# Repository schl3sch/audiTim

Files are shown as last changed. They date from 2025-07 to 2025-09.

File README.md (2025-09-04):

# 🎧 audiTim – SE-Projekt Code-Repository
Dies ist das zentrale Code-Repository für unser Software-Engineering-Projekt **audiTim**.

📝 **👉 Projektdokumentation:**  
Alle Details zur Idee, Architektur, Technik und Ergebnissen befinden sich in der hier beiligenden Dokumentation:  
📎 ./Documentation/ProjektSe/dokumentation.pdf

## 🛠️ Projekt bauen
1. `.env` konfigurieren (siehe `template.env`)
2. Netzwerk erstellen:
    ```bash
    docker network create sensor-net
    ```
3. Container bauen und starten:
    ```bash
    docker compose up --build -d
    ```
4. In [NodeRed](http://localhost:1880) die InfluxNode konfigurieren
5. [Frontend](http://localhost:8081) öffnen

Ports:
- [Frontend](http://localhost:8081)
- [NodeRed](http://localhost:1880)
- [InfluxDB](http://localhost:8086)

## 📐 Programmierkonventionen
Bitte achtet auf folgende grundlegende Regeln im Projekt:

### Allgemein
-  Klare Projektstruktur: Trennung von `frontend`, `backend`, `firmware`, `tools` etc.
-  Sinnvolle Dateinamen, keine Leerzeichen oder Sonderzeichen
-  Kein Code ohne Nutzen: Altlasten & toten Code entfernen
-  sprechende englische Variablen-/Funktionsnamen

### Code-Stil
- **C++ (ESP32):**
  - Einrückung mit 2 Leerzeichen
  - CamelCase für Variablen und Funktionen
  - Funktionskommentare mit im Stil `CODE // Kommentar ` 
- **Python:**
  - PEP8-konform
  - Docstrings für alle Funktionen und Klassen
- **JavaScript/TypeScript:**
  - ESLint-konformer Stil
  - Klar benannte Funktionen & Kommentare bei komplexer Logik

### Code-Richtlinien
- **C++ (ESP32):**
  - Kein Serial.print in finalem Sketch (Braucht zu lange)
  - Kein \#define -> nur const (Einheitlich)
  - Kein while(!init){} (Nicht benötigt)
  - Funktion probeMax4466 muss in den Dateien identisch sein
  - Externe Bibliotheken müssen mit Version angegeben sein

## Testing
docker-compose -d -build --prod um tests in docker laufen zu lassen!

### E2E-Testing 
npx playwright install to install Browsers locally
npx playwright test to run tests
npx playwright test --ui for ui 
npx playwright test --headed for open Browser on testing
npx playwright codegen http://localhost:8081 for testgenerator im Durchlauf

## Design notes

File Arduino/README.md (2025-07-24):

# 🎧 audiTim – SE-Projekt Code-Repository

Dies ist das zentrale Code-Repository für unser Software-Engineering-Projekt **audiTim**.

📝 **👉 Projektdokumentation:**  
Alle Details zur Idee, Architektur, Technik und Ergebnissen befinden sich im zugehörigen Doku-Repository:  
📎 [https://github.com/JD-GG/audiTim-Documentation.git](https://github.com/JD-GG/audiTim-Documentation.git)

## 📐 Programmierkonventionen

Bitte achtet auf folgende grundlegende Regeln im Projekt:

### Allgemein

-  Klare Projektstruktur: Trennung von `frontend`, `backend`, `firmware`, `tools` etc.
-  Sinnvolle Dateinamen, keine Leerzeichen oder Sonderzeichen
-  Kein Code ohne Nutzen: Altlasten & toten Code entfernen
-  sprechende englische Variablen-/Funktionsnamen

### Code-Stil

- **C++ (ESP32):**
  - Einrückung mit 2 Leerzeichen
  - CamelCase für Variablen und Funktionen
  - Funktionskommentare mit im Stil `CODE // Kommentar ` 
- **Python:**
  - PEP8-konform
  - Docstrings für alle Funktionen und Klassen
- **JavaScript/TypeScript:**
  - ESLint-konformer Stil
  - Klar benannte Funktionen & Kommentare bei komplexer Logik

### Code-Richtlinien

- **C++ (ESP32):**
  - Kein delay() nach WiFi init (Stört WiFi)
  - Kein Serial.print in finalem Sketch (Braucht zu lange)
  - Kein \#define -> nur const (Einheitlich)
  - Kein while(!init){} (Nicht benötigt)
  - Funktion probeMax4466 muss in den Dateien identisch sein
  - Externe Bibliotheken müssen mit Version angegeben sein

## 🔀 Git-Workflow (Feature-Branch-Modell)

Wir arbeiten mit einem **Feature-Branch-Modell**, um saubere und nachvollziehbare Entwicklung zu gewährleisten.

### Branches

- `main`: stabile, getestete Versionen
- `feature/<kurzer-namer>´: jeweiliger Feature-Branch

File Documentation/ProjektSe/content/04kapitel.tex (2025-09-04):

\chapter{Softwarekomponenten}

\section{Entwicklungsumgebungen}

Zu Beginn des Projekts wurden zwei gängige Entwicklungsumgebungen für die Programmierung von Mikrocontrollern evaluiert: die klassische \textit{Arduino IDE}, welche auch von den betreuenden Dozierenden empfohlen wurde, sowie die moderne, zunehmend verbreitete \textit{PlatformIO}-Erweiterung für Visual Studio Code.
Im Projektteam wird plattformübergreifend mit Linux, Windows 10 und Windows 11 gearbeitet. Beide Entwicklungsumgebungen sind grundsätzlich mit allen eingesetzten Betriebssystemen kompatibel. Zur Prüfung der technischen Umsetzbarkeit wurden zwei separate Repositories eingerichtet, in denen jeweils einfache Testprojekte zur Ansteuerung eines ESP32 implementiert wurden.
Beide IDEs konnten den Mikrocontroller erfolgreich ansprechen. PlatformIO bietet durch seine deklarative Verwaltung von Bibliotheken und Abhängigkeiten Vorteile in Bezug auf Reproduzierbarkeit und Build-Konsistenz. In der Praxis kam es jedoch auf einem System im Team zu anhaltenden technischen Problemen mit PlatformIO, die nicht zufriedenstellend gelöst werden konnten.
Um eine einheitliche und zuverlässige Entwicklungsgrundlage für alle Teammitglieder sicherzustellen, fiel die Entscheidung letztlich zugunsten der \textit{Arduino IDE}. Diese ermöglicht eine barrierefreie Mitarbeit aller Beteiligten, auch wenn sie im Funktionsumfang nicht ganz an PlatformIO heranreicht.

\section{Kommunikationsmethode}
ESP-NOW wurde ausgewählt, da es im Vergleich zu anderen Protokollen einen deutlich geringeren Overhead besitzt und dadurch eine schnellere und effizientere Datenübertragung ermöglicht. Die Struktur ist weniger komplex, was die Implementierung vereinfacht und die Fehleranfälligkeit reduziert. 
Dadurch wird das System insgesamt robuster und zuverlässiger:
ESP-Now ist ein Kommunikationsprotokoll von Espressif, das speziell für die ESP32- und ESP8266-Chips entwickelt wurde. Es verwendet die 2,4 Ghz Frequenz, welche eigentlich für WiFi Kommunikation verwendet wird. 
Im Gegensatz zu anderen Protokollen sind die Nachrichten auf Schicht 2 des ISO-OSI-Modells. Keine IP-Adressen sondern nur MAC-Adressen. Die ESPs müssen sich dafür im gleichen Kanal befinden. Die 2,4 Ghz Frequenz hat grundsätzlich nur 3 Nutzbare Kanäle. 
Der zu verwendene Kanal muss von dem "AI401" Wlan Netz übernommen werden.Es ist mit relativ wenig Code möglich eine große Menge an Daten in sehr Kurzen Zeitabschnitten zu senden. Theoretisch ist eine Datenübertragung von 1 bis 2 Mbps möglich. 
Die Nachrichtenlänge ist auf 250 Byte pro Paket beschränkt. Da unsere Nachrichten nur wenige Bit lang sind, haben wir hier keine Probleme. 
Das Protokoll hat keine festgelegten Sender/Empfänger Rollen. Jeder ESP kann senden und empfangen. In unserem Beispiel senden aber 3 ESPs und ein Edge-Device empfängt alle Daten. 
Es wird 10 mal pro Sekunde der Lautstärkepegel erfasst und gesendet.

\section{Frontend}
\subsection{Technologieauswahl}
Für die Umsetzung des Frontends wurde das Framework \textit{Angular} gewählt. 
Diese netschiedung basiert auf technischen Faktoren und persönlichen Preferenzen. 
Angular bietet eine klare Struktur durch komponentenbasiertes Design und ist für die moderne Webentwicklung gut geeignet.
Es erleichtert die Wiederverwendbarkeit von eigenen aber auch externen UI-Elementen und unterstützt eine saubere Trennung von Logik und Darstellung. 

Im Vergleich dazu ist \textit{React} ein von Meta entwickeltes UI-Framework. 
\textit{Angular} und \textit{React} haben beide eine komponentenbasierte Architektur. 
Diese Komponenten sind innerhalb anderer Komponenten wiederverwendbar und somit endlos wiederverwertbar. 
Beide sind Open Source. Daher haben React und Angular große Entwicklergemeinschaften, die die Ressourcen regelmäßig erweitern.
Angular ist ein vollwertiges Framework, während React eine JavaScript-Bibliothek ist. 
Deshalb muss React mit einem Framework gepaart werden, um eine schnelle, schöne und kompatible Benutzeroberfläche zu erstellen. 
\cite{kinsta2023angularvreact}

Da außerdem im Team bereits umfangreiche Erfahrung mit diesem Framework vorhanden war, fiel die Entscheidung zugunsten von Angular.
Das Frontend läuft in einem eigenen Docker-Container und kommuniziert, über ein internes Netzwerk, mit dem separat laufenden Backend-Container. 
So bleibt die Architektur modular, skalierbar und einfach wartbar.

\subsection{Umsetzungsplan}
Während der Entwicklung wurde ein einfaches Frontend zu Testzwecken angelegt. 
Deshalb soll nun ein Plan entwickelt werden, wie die Benutzeroberfläche aussehen soll und welche Funktionen sie bieten soll:
\begin{center}
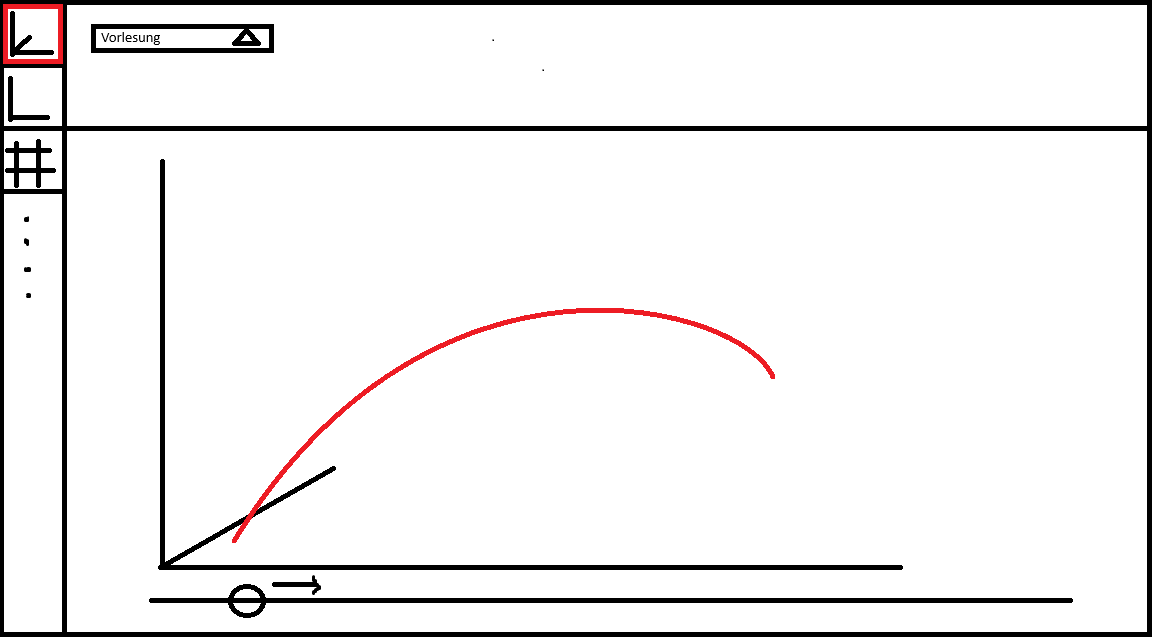
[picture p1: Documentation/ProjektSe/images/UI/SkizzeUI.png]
  
\end{center}
In dieser Skizze wurden die Grundfunktionen der Benutzeroberfläche festgelegt und die Anordnung der einzelnen Elemente skizziert.
Über eine Navbar an der linken Seite kann zwischen den einzelnen Seiten gewechselt werden. 
Auf der Hauptseite wird eine Heatmap angezeigt, die die Lautstärkeverteiung im Vorlesungsraum räumlich darstellt, wobei mit einem Dropdown-Menü der anzuzueigende Zeitraum ausgewählt werden kann.
Durch den ausgewählten Zeitraum kann anschließend mit einem Schieberegler die Zeit ausgewählt werden, für die die Lautstärke angezeigt werden soll.
Im nächsten Nav-Item sollen die einzelnen 2D-Grafen der jeweiligen Sensoren angezeigt werden. 
Das dritte Nav-Item soll einen tabellarischen Überblick über die gesammelten Daten geben, die in der Datenbank gespeichert sind.
Die Nvabar bietet Raum für zukünfitge Erweiterungen.

\subsection{Umsetzung}
Auf Grundlage dieser Skizze wurde das Frontend und UI efolgreich umgesetzt.
So hat man nun eine übersichtliche Homepage, die auf alle Elemente verweist, welche auch in der interaktiven Navbar zu finden sind.
Als kleines AddOn wurde unteranderem hierfür ein "AudiTim" Logo entworfen, was den ikonischen Hirsch mit dem vernetzten Geweih und den Audiowellen verknüpft, sowie eine Light- und Darkmode Funktionalität implementiert.
\begin{center}
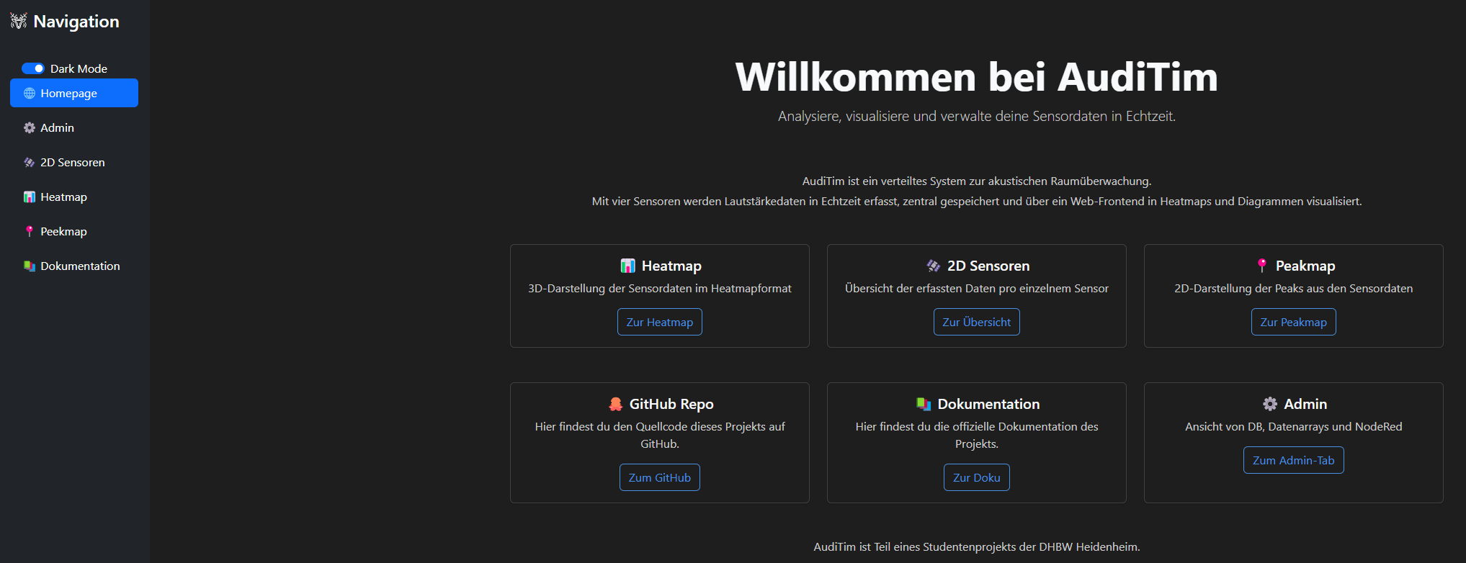
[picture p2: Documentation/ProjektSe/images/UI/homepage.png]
  
\end{center}

Auch im Screenshot zu sehen, sind die schlussendlich umgesetzten Seiten; Heatmap, 2D-Sensoren, Peakmap, Github Repo, Dokumentation und Admin. 
Für diese Seiten wurden die in der Skizze angedachten Funktionen erfolgreich umgesetzt und flexibel während der Entwicklung angepasst und erweitert.

So zeigt die Admin-Seite nun eine Übersicht über die verbundenen Container und Elemte sowie deren Status an:
\begin{center}
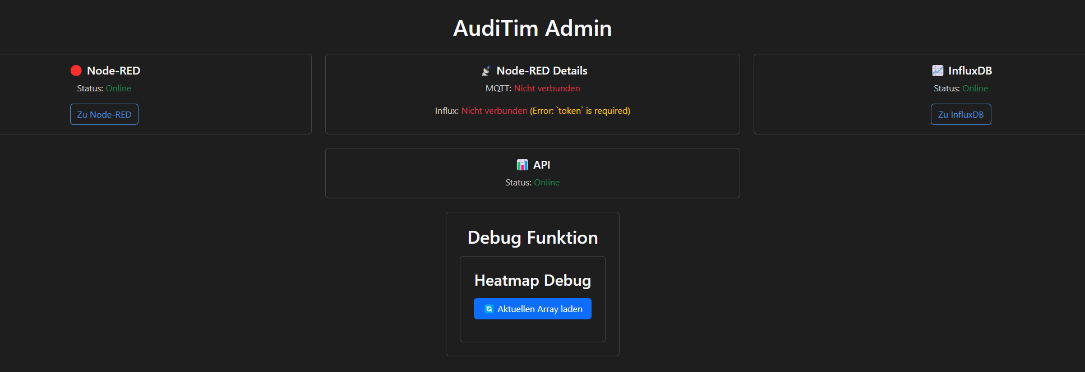
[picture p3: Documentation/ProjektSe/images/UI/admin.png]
  
\end{center}

Die 2D-Sensoren-Seite zeigt die einzelnen Sensorwerte in übersichtlichen Liniendiagrammen an, wobei man zwischen einem ausgewählten Zeitraum und einem Live-Modus wechseln kann:
\begin{center}
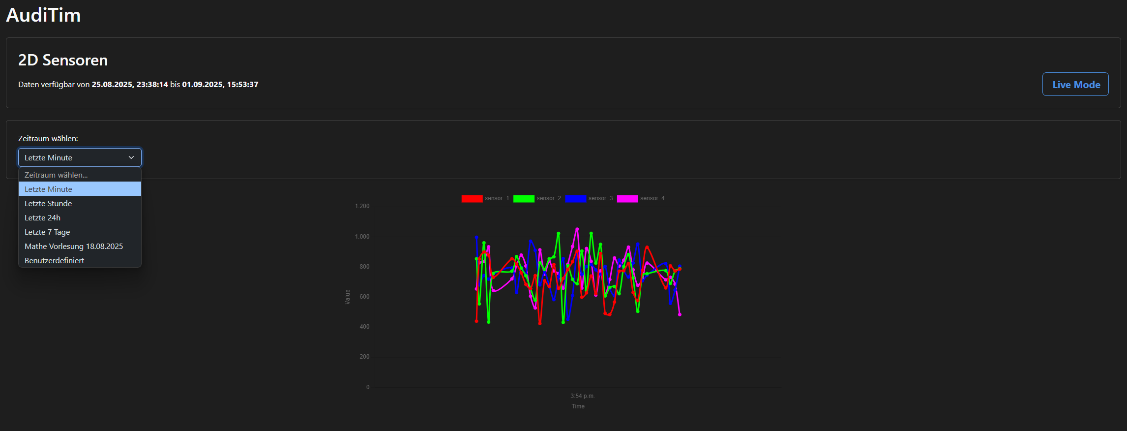
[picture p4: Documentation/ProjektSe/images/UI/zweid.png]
  
\end{center}

Auch die Heatmap-Seite zeigt die Auswahl zwischen einem ausgewählten Zeitraum und einem Live-Modus, sowie einen Average-Modus, in dem die durchschnittliche Lautstärke über den ausgewählten Zeitraum angezeigt wird. 
Mit einem Schieberegler kann die Zeit innerhalb des ausgewählten Zeitraums angepasst werden und gegenenenfalls eine Animation gestartet werden, die die Lautstärkeverteilung über den Zeitraum hinweg anzeigt.
Außerdem wurde das in "4.5 3D-Raummodellierung" beschriebene 3D-Modell des Raumes als Hintergrundbild für die Heatmap verwendet, um eine realistische Darstellung zu ermöglichen:
\begin{center}
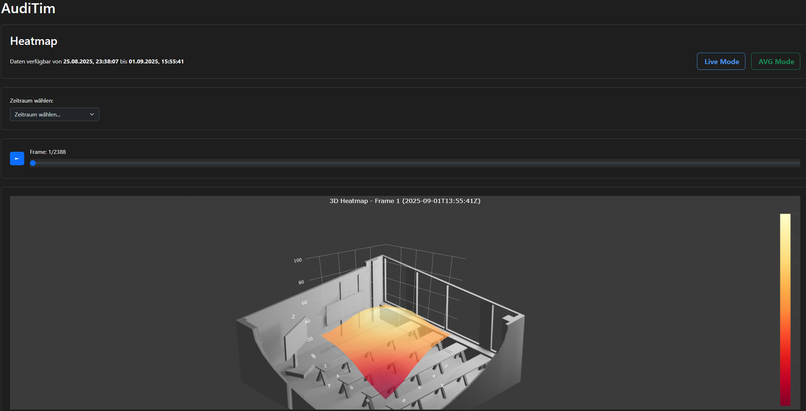
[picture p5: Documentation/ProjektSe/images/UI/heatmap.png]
  
\end{center}

Dieses 3D-Modell wurde auch für die Peakmap-Seite verwendet, auf der die Spitzenwerte der Sensoren über den ausgewählten Zeitraum angezeigt werden:
\begin{center}
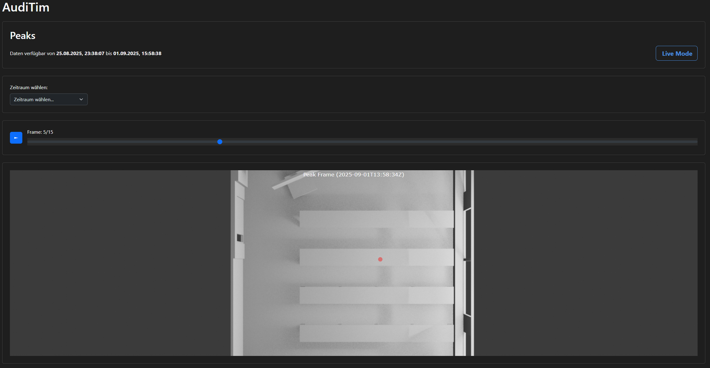
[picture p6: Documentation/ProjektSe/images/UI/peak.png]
  
\end{center}

Und zu guter Letzt zeigt die Dokumentation-Seite diese Dokumentation, die sie hier gerade lesen, in einem eingebetteten PDF-Viewer an. 

\subsection{Testing}
Für die Umsetzung des automatisierten Testings wurde Playwright eingesetzt. Die Auswahl dieses Frameworks erfolgte nach einer vergleichenden Analyse. Dabei wurde Playwright von einem Teammitglied im Rahmen einer Projektarbeit mit einem ähnlichen Anwendungsfall ausführlich evaluiert und als am geeignetsten bewertet. Ausschlaggebend hierfür waren insbesondere die breite Browserunterstützung, die integrierten Funktionen für End-to-End-Tests sowie die hohe Stabilität und Geschwindigkeit der Testausführung.

Durch den Einsatz von Playwright konnte die Konsistenz der Benutzeroberfläche (UI) zuverlässig sichergestellt werden. Die automatisierten Tests ermöglichen es, Interaktionen und Darstellungsvarianten reproduzierbar zu prüfen und so frühzeitig Abweichungen oder Fehler zu erkennen. Auf diese Weise trägt das Testing wesentlich zur Qualitätssicherung und Nachhaltigkeit der entwickelten Lösung bei.

\section{Backend}
Das Backend wurde mit Node.js und dem minimalistischen Framework Express.js umgesetzt. 
Express ist das am weitesten verbreitete Node.js-Framework für Webserver und APIs. 
Es bietet eine ausgereifte Middleware-Architektur, die sehr flexibel und modular ist. 
Im Vergleich zu ähnlich minimalistischen Frameworks wie Koa, 
das von den gleichen Entwicklern stammt, 
bietet Express mehr out-of-the-box Funktionalitäten und eine größere Community mit umfangreichen Plugins und Support. \cite{betterstack2025koavsexpress,appventurez2025nodejsframework}

Koa hingegen ist moderner und basiert stärker auf ES6 Features wie async/await, was den Code oft sauberer macht. 
Allerdings ist Koa weniger „batteries included“ und erfordert mehr Initialaufwand und zusätzliche Libraries, 
um Funktionen bereitzustellen, die Express standardmäßig mitbringt. 
Für dieses Projekt, welches einen schnellen Einstieg, umfangreiche Dokumentation und stabile Middleware braucht, 
ist Express daher die pragmatischere Wahl.
Zudem sind Gruppenmitglieder bereits mit Express vertraut, was die Einarbeitungszeit verkürzt und die Produktivität steigert. 

Die Anbindung an eine InfluxDB erfolgt über die offizielle Client-Bibliothek. 
Neben dem Abrufen historischer Sensorwerte werden auch Funktionen zum Schreiben von Dummy-Daten bereitgestellt.
Diese werden, solange die Verbindung zu den wirklichen Sensorwerten noch nicht hergestellt ist, zum Testen verwendet.

Für die Speicherung der Sensordaten wurde InfluxDB gewählt. 
Eine Zeitreihen-Datenbank, die speziell für viele konsekutive Datenströme optimiert ist. 
InfluxDB bietet eine simple API und gutes visuelles UI, ohne dass viel Konfiguration nötig ist.
Im Vergleich zu einer relationalen Datenbank wie TimescaleDB, die auf PostgreSQL basiert,
ist InfluxDB deutlich einfacher zu handhaben und benötigt weniger Overhead für die Konfiguration.
Um eine TimescaleDB sicher zum laufen zu bringen, sind komplexe Zugriff-Skripte benötigt, um die Benutzer zu verwalten.
InfluxDB hingegen arbeitet mit einem einfachen Benutzer- und Rollenkonzept. 
Auch für die API-Authentifizierung ist InfluxDB mithilfe von Tokens und Secrets deutlich einfacher zu konfigurieren.
Der Rationale Aspekt einer traditionellen ist sicherlich in vieler Hinsicht nützlich, wird aber in diesem Projekt nicht benötigt.
Eine nahtlosen Integration in das Node.js-Backend ist mit der offiziellen InfluxDB-Bibliothek kein Problem.
InfluxDB wurde uns initial von den "Verteilten Systeme"-Dozenten ausdrücklich empfohlen, da wir viele Zeitwerte speichern und analysieren wollen.

\subsubsection*{Berechnung des Speicherplatzbedarfs für InfluxDB}

Zur Abschätzung des benötigten Speicherplatzes in InfluxDB betrachten wir die anfallenden Sensordaten pro Stunde.  

\paragraph{Rohdaten}  
Pro Sekunde werden \textbf{10 Messungen} von \textbf{4 Sensoren} erfasst, wobei jeder Wert als \texttt{double} (64\,Bit = 8\,Byte) gespeichert wird.  
Damit ergibt sich:  

\[
10 \times 4 \times 8 \,\text{Byte} \times 60 \times 60 
= 1{,}152{,}000 \,\text{Byte} \approx 1.1 \,\text{MB/h}
\]

\paragraph{Base64-kodierte Daten}  
Wird der Algorithmus auf die Sensordaten angewendet, erzeugt er daraus ein 10x10-Array mit Werten im Bereich von 0 bis 255. Dieses Array wird anschließend kodiert. Durch die Base64-Kodierung entsteht dabei ein Overhead von etwa 36\%. Für die Datenmenge ergibt sich pro Sekunde:  

\[
800 \,\text{Bit} = 100 \,\text{Byte} \quad \Rightarrow \quad 
\text{mit Overhead} \approx 136 \,\text{Byte}
\]

Somit pro Stunde:  

\[
136 \,\text{Byte} \times 60 \times 60 
= 489{,}600 \,\text{Byte} \approx 470 \,\text{KB/h}
\]

\paragraph{Fazit}  
Für die Speicherung in InfluxDB müssen daher pro Stunde etwa  
\[
1.1\,\text{MB (Rohdaten)} + 0.47\,\text{MB (Base64)} \approx 1.6\,\text{MB/h}
\]  
eingeplant werden.

Das Backend ist ebenfalls in einem eigenen Docker-Container gekapselt. 
Die Kommunikation mit dem Frontend erfolgt über definierte HTTP-Endpunkte im Container-Netzwerk. 
Diese Trennung verbessert die Wartbarkeit und erlaubt eine flexible Skalierung beider Komponenten unabhängig voneinander.

\section{MQTT Subscriber}
Um den Datenfluss zu verfollständigen fehlt eine Brücke zwischen dem MQTT Server und der InfluxDB. 
Hierfür wird ein sogenannter MQTT-Subscriber benötigt, der die Daten vom MQTT-Broker abonniert und in die InfluxDB schreibt.
Technisch gesehen kann dies mit einer vielzahl von Frameworks / Sprachen / Tools umgesetzt werden. 
Zum Beispiel mit Python, Node.js, Golang oder auch Java.
Wir haben uns für Node-RED entschieden, da es eine einfache und schnelle Möglichkeit bietet, um Daten von MQTT zu InfluxDB zu übertragen.
Node-RED ist eine visuelle Programmierumgebung, die auf Node.js basiert und es ermöglicht, Datenströme einfach zu verarbeiten und zu transformieren.
Besonders das debugging und die Visualisierung der Datenströme ist in Node-RED sehr einfach und intuitiv.
\cite{nodered2023docs}

Im Vergleich zu z.B. einem Python-Skript ist Node-RED deutlich einfacher zu handhaben.
Natürlich ist Node-RED nicht so performant oder bietet dieselbe Flexibilität und Kontrolle wie ein selbstgeschriebenes Skript,
ist aber dafür deutlich einfacher zu konfigurieren und zu warten.
Besonders in unserem spezifischen Fall, wo wenig Kontrolle über den schlussendlichen Server besteht, ist Node-RED eine gute Wahl.
Eine automatische Ausführung von Skripten ist beinahe unmöglich, das keine Kontrolle über Sudo-Level Systemdiensten besteht.

\subsection{NodeRED Umsetzung}
Node-RED stellte sich als eine gute Entscheidung heraus, um den Flow zwischen MQTT und InfluxDB zu realisieren, und aber auch um bspw. Statusanfragen für die Admin-Seite zu beantworten.
Das einzige Manko war das ständige Erneuern der Tokens für die InfluxDB, da Node-RED keine Möglichkeit bietet, Umgebungsvariablen zu verwenden.
Schlussendlich entstand ein gut-funktionierender Flow:
\begin{center}
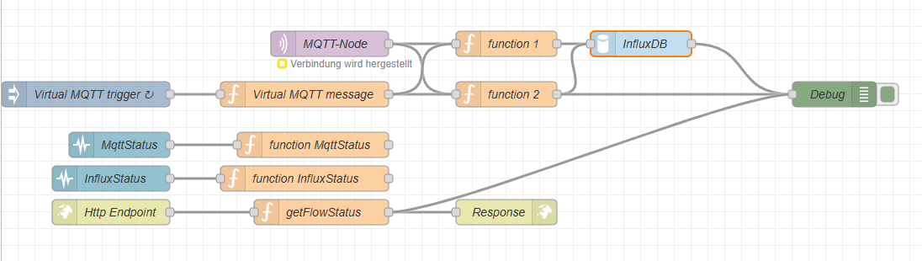
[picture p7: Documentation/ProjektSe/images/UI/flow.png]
  
\end{center}

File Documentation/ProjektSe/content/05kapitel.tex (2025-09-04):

\chapter{Befestigung der Hardware}
\label{chap:Befestigung_der_Hardware}
Um die Hardware des AudiTim-Systems sicher und stabil zu befestigen, sind verschiedene Montagemöglichkeiten verfügbar. 
Ein Großes Problem bei vorgefertigten halterungen ist jedoch, dass diese oft an die and geschraubt oder anderweitig befestigt werden müssen.
Daher fiel für unser Projekt die wahl auf eine selbst designte Halterung, welche in einem 3D-Drucker hergestellt werden kann.
Dies Garantiert dass keine schäden an der Hardware oder am Raum in welchem die Hardware montiert wird entstehen.

\section{Platzungskonzept}
Aus akustischer Sicht liefern Messungen die zuverlässigsten Ergebnisse, wenn die Sensoren auf Kopfhöhe im Sitzen (~1,2-1,5 m Höhe) angebracht sind und mindestens 1 Meter Abstand zu Wänden und der Schallquelle haben. 
Dieses Vorgehen minimiert frühe Reflexionen, stehende Wellen und lokale Pegelabweichungen - Faktoren, die die Messgenauigkeit maßgeblich beeinträchtigen \cite{oltheten2019micplacement} .
Leider ist diese ideale Positionierung in unserem Fall praktisch nicht umsetzbar. So birgt Montage am Boden, Tischen oder gesonderte "Ständer" erhöhte Gefahr von Beschädigungen, Verschiebungen und Manipulation.
An der Decke jedoch beifinden sich bereits vorhandene Löcher; diese können genutzt werden, um die Sensoren und den Mikrocontroller sicher zu befestigen. 
Auch den einen Meter Abstand zu Wänden und Schallquellen kann so eingehalten werden.
Dieser Kompromiss ermöglicht eine schützende, wartungsarme und vergleichbare Positionierung der Sensoren.
So bleibt der Messaufbau reproduzierbar, sicher und funktional, auch wenn die akustisch ideale Lösung nicht vollständig umsetzbar ist.

\section{Deckenhalterung}
Um die Hardware an der Decke zu befestigen, wurde eine spezielle Halterung entworfen, die eine sichere Montage ermöglicht.
Diese Halterung nutzt die in den Decken vorhandenen "Löcher" für die Montage und wurde als eine Art Pin konzipiert.

\begin{center}
  \begin{minipage}[b]{0.32\textwidth}
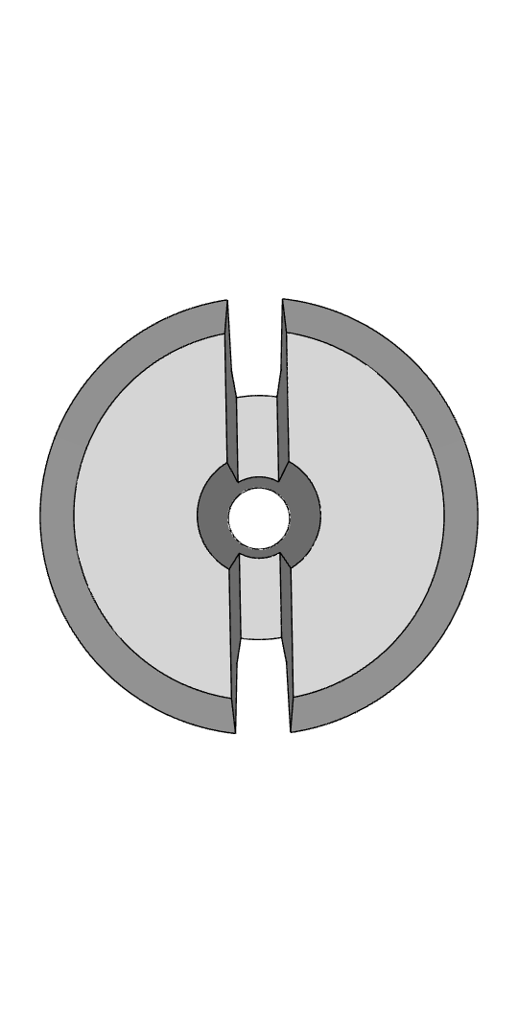
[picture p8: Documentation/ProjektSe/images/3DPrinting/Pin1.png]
    
  \end{minipage}
  \hfill
  \begin{minipage}[b]{0.32\textwidth}
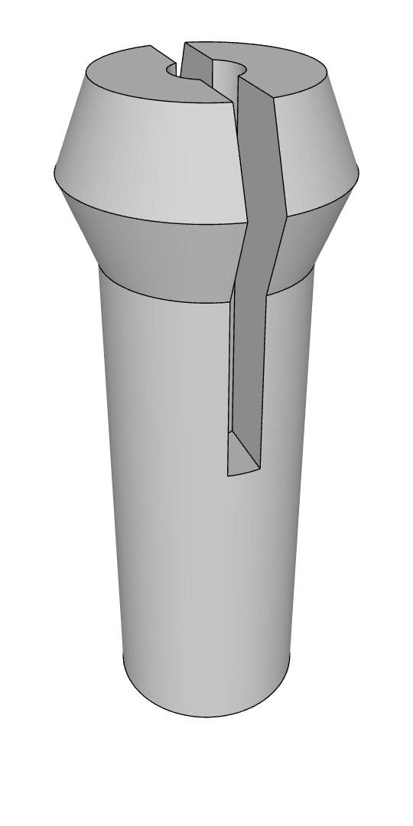
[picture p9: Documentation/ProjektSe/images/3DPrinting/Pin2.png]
    
  \end{minipage}
  \hfill
  \begin{minipage}[b]{0.32\textwidth}
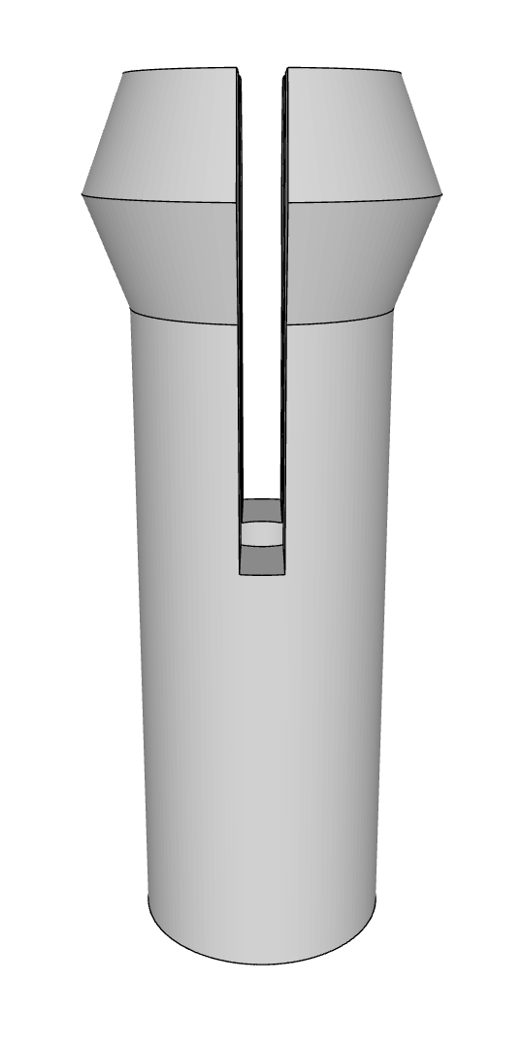
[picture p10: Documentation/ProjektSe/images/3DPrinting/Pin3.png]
    
  \end{minipage}
\end{center}

Der in den Bildern Dargestellte Pin kann durch den Spalt in der Mitte in die öffnung der Decke gesteckt werden.
Durch die Konische form der Spitze des Pins wird garantiert dass dieser auch bei der Demontage des Projekts keine schäden hinterlässt.
Das runde loch welches sich durch den Pin zieht dient dazu, den Pin mit einer Schraube an der Hardware zu befestigen.

\section{ESP32-Halterung}
Der Esp benötigt eine Box welche sicher an der Decke mit den Pins befestigt werden kann.
Bei dem Design der Box wurde sich an einigen Vorlagen orientiert um eine optimale Passform zu gewährleisten.
Die Box ist so gestaltet, dass sie den ESP32 sicher hält und gleichzeitig genug Platz für die Verkabelung bietet.

\begin{center}
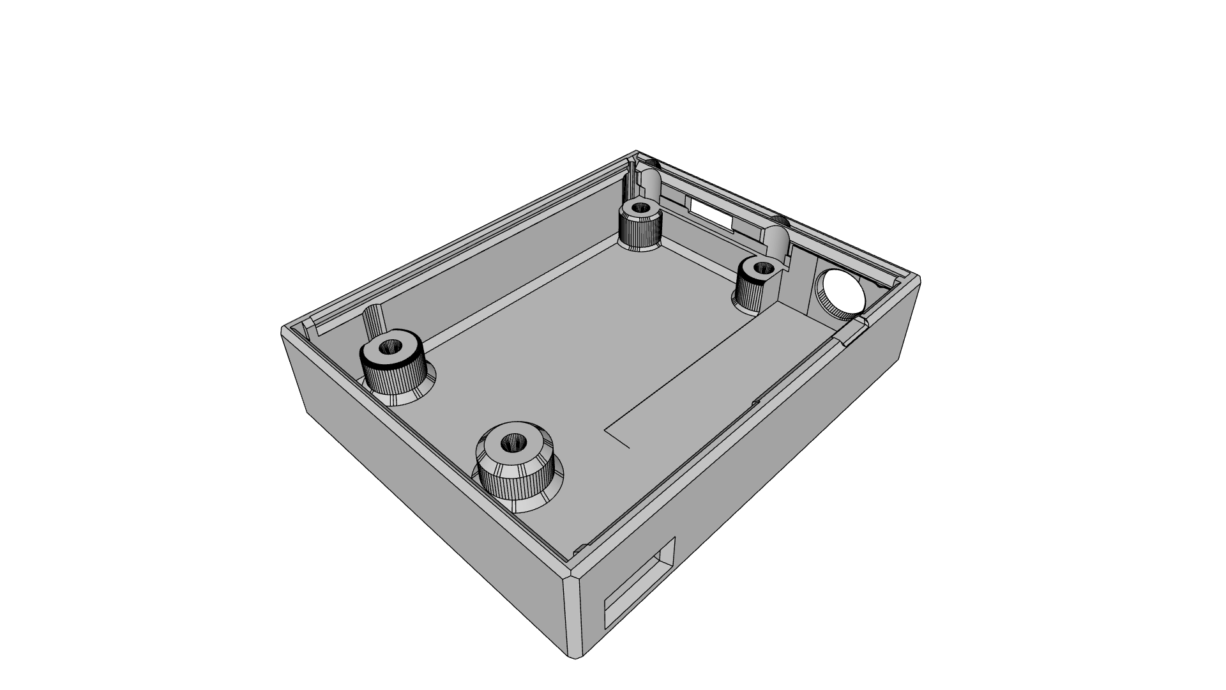
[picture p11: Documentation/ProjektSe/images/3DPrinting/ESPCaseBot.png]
  
\end{center}

Die angesprochenen löcher der Pins kommen in der Decke der Box zum Einsatz, um die Box sicher an der Decke zu befestigen.
Diese werden durch die löcher in der Decke mit schrauben von innen befestigt.

\begin{center}
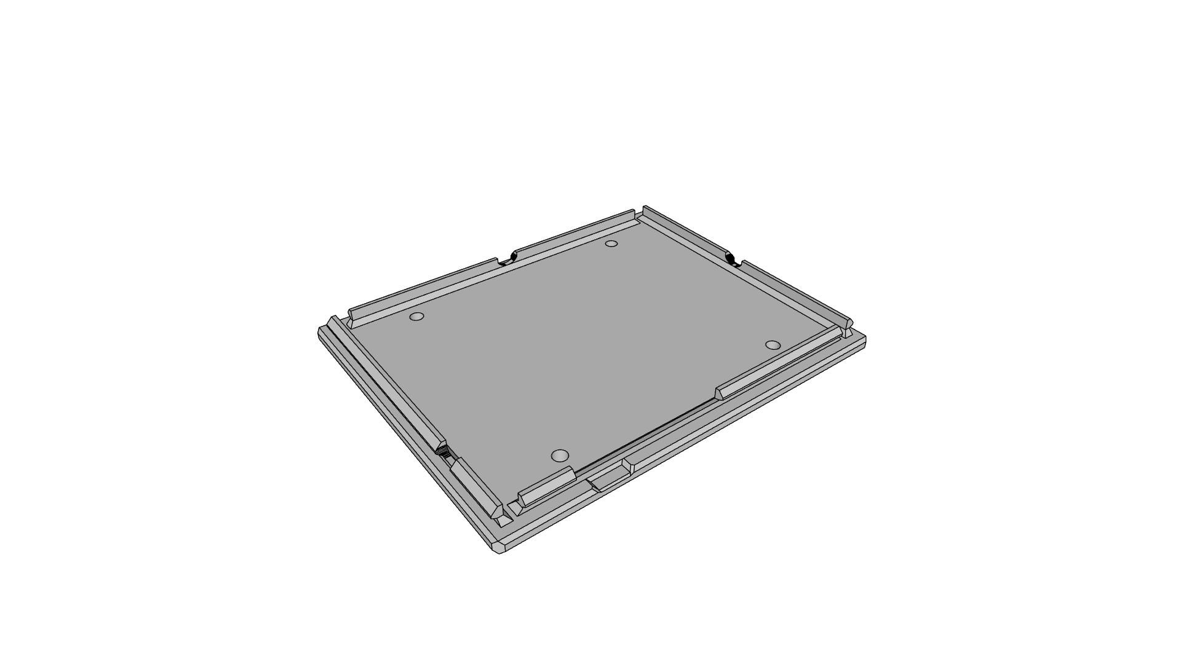
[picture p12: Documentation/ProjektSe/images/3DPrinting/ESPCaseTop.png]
  
\end{center}

\section{Sensor-Halterung}

Die Sensorhalterung wurde so entworfen dass sie platz für einen möglichen Dämpfer bietet,
welcher um das Mikrofon befestigt werden kann.
Auch diese Halterung wird mit den Pins an der Decke befestigt, jedoch wird sie nicht geschraubt sondern direkt mit den Pins gedruckt.
Der Sensor wird dann einfach mit zwei schrauben an der Halterung befestigt.

\begin{center}
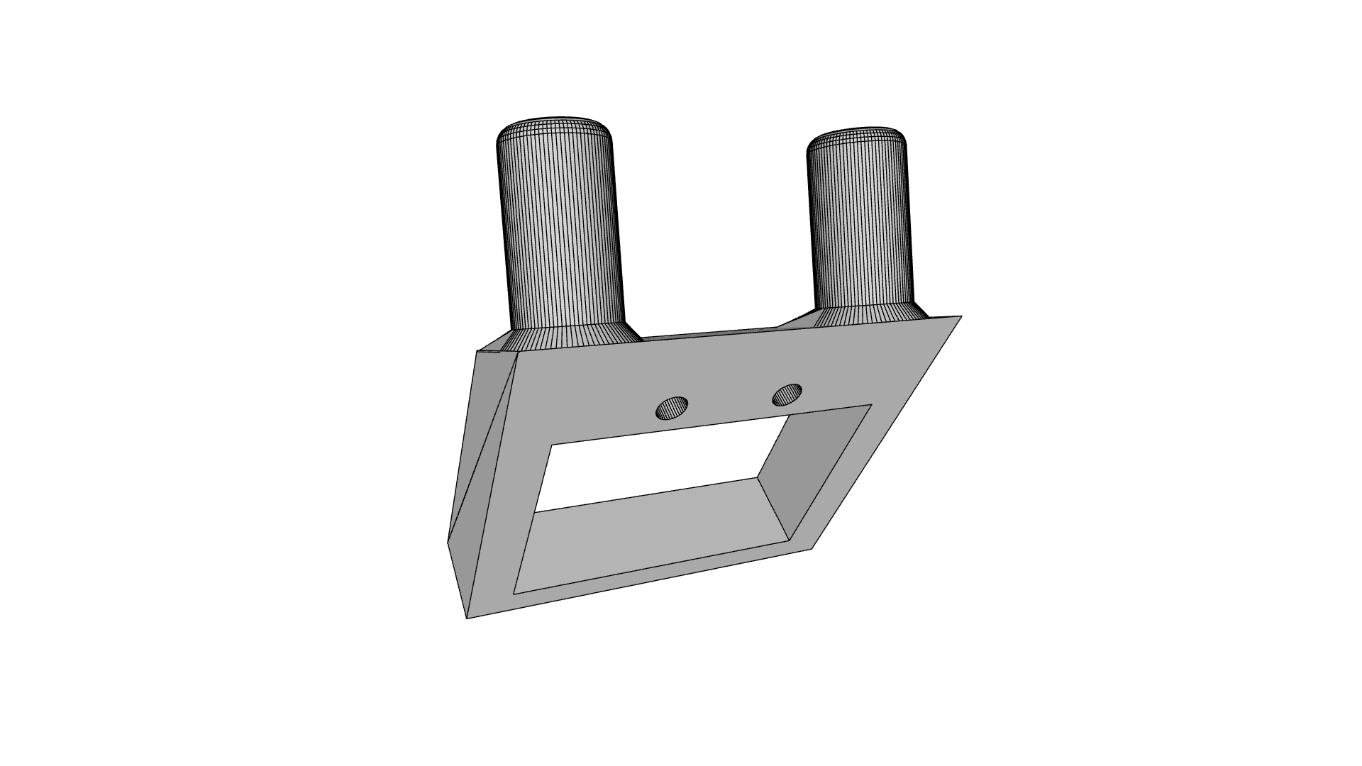
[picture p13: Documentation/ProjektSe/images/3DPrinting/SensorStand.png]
  
\end{center}

\section{3D-Raummodellierung}
Um eine grafische Übersicht der Montage der ESPs und Sensoren zu erhalten, wurde ein 3D-Modell des Raumes erstellt.
Außderdem soll dieses später als Grundlage für die Simulation der Schallausbreitung als Hintergrund für die Heatmap im Frontend dienen.
Dafür wurde vorerst der Vorlesungsraum ausgemessen und in einer technischen Zeichnung festgehalten:
\begin{center}
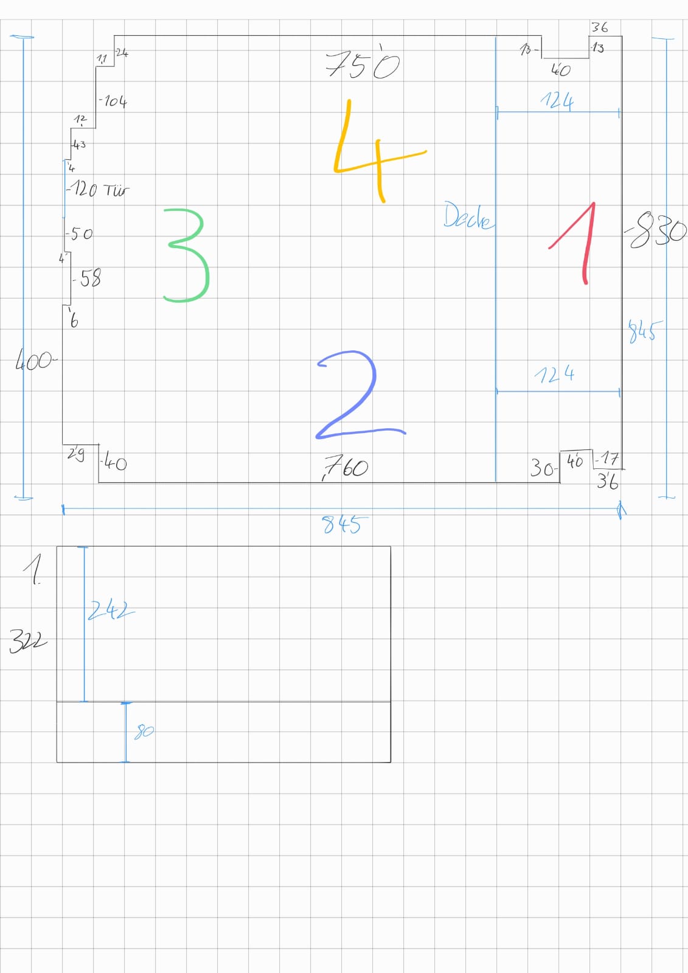
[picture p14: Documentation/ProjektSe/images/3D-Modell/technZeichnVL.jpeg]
  
\end{center}
Diese Zeichnung dient als Grundlage für die 3D-Modellierung des Raumes, welche in Blender durchgeführt wurde:
\begin{center}
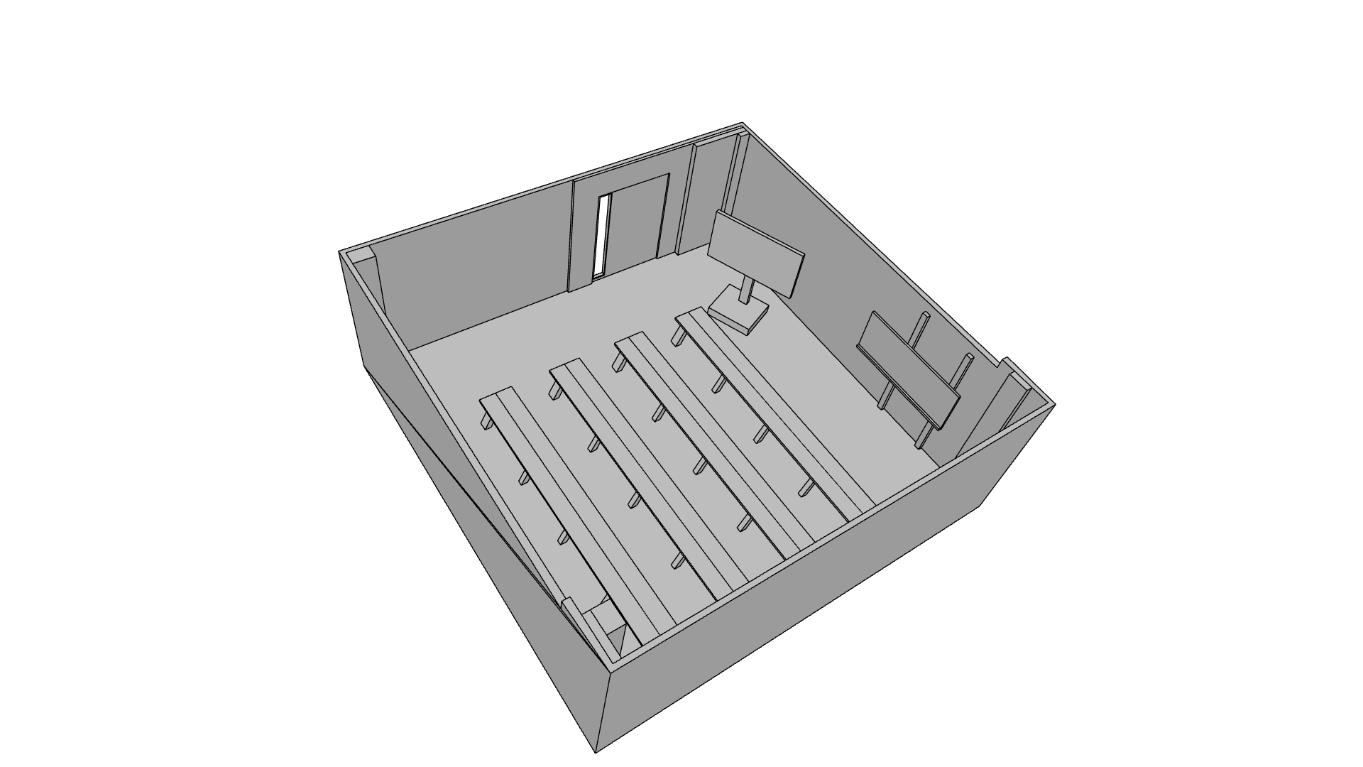
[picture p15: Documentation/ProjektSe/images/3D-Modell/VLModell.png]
  
\end{center}

\paragraph{Hinweis zur Nutzung der 3D-Modelle}  
Die im Projekt erstellten Blender-Dateien und Halterungen können direkt für den 3D-Druck verwendet werden.  
Zum Export der STL-Dateien ist im Blender-Menü der Pfad \texttt{audiTim/Blender/Printable} zu wählen.

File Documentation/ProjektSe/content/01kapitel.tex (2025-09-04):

\chapter{Einleitung}
\label{cha:einleitung}

Im Rahmen des Software-Engineering-Projekts wird in einem Team ein System zur akustischen Raumüberwachung entwickelt. 
Ziel des Projekts ist die kontinuierliche Erfassung und spätere Analyse der Lautstärkeverteilung in einem typischen Vorlesungsraum über den Zeitraum mehrerer Tage hinweg.

\section{Projektüberblick}

Die Umsetzung erfolgt nach agilen Prinzipien unter Anwendung von Scrum, wobei die jeweiligen Sprints von Freitag bis Freitag festgelegt wurden. 

Die technische Architektur sieht den Einsatz von vier Mikrocontroller-Einheiten (ESP32) vor, die jeweils mit einem Mikrofon oder einem Dezibel-Messsensor ausgestattet werden. 
Die Geräte werden in den vier Ecken des Vorlesungsraums positioniert, um eine möglichst flächendeckende Abdeckung des Raumes zu gewährleisten. Über ein Kommunikationsprotokoll tauschen sich die ESPs untereinander aus und 
senden die gesammelten Messdaten gemeinsam an ein zentrales Backend.

\section{Ziele und Motivation}

Ziel ist es, ein skalierbares und robustes System zu entwickeln, das Lautstärkepegel über einen längeren Zeitraum erfassen kann. Die gesammelten Daten sollen im Backend gespeichert und im Nachgang analysiert werden. 
Hierbei sind verschiedene Darstellungsformen wie etwa Heatmaps oder zeitbasierte Diagramme denkbar, um Muster oder Auffälligkeiten im akustischen Verhalten des Raumes sichtbar zu machen.

\section{MVP und Qualitätsmerkmale}

Im Rahmen des MVPs soll ein verteiltes System zur akustischen Raumüberwachung auf Basis von vier Mikrocontrollern der ESP-Serie entwickelt werden. 
Jeder ESP wird über ein extern angeschlossenes Mikrofon verfügen, mit dem kontinuierlich Lautstärkedaten erfasst werden. Drei der Module sollen ihre Messwerte mithilfe des ESP-NOW-Protokolls an eine zentrale Einheit übermitteln, 
die zusätzlich eigene Daten erfasst. Die aggregierten Informationen aller vier Einheiten werden in festen Intervallen über das MQTT-Protokoll an einen Server gesendet und dort zeitsynchron in einer InfluxDB gespeichert. 
Über eine REST-API sollen die Daten einem Angular-basierten Web-Frontend zur Visualisierung der akustischen Messwerte zur Verfügung gestellt werden.

\begin{center}
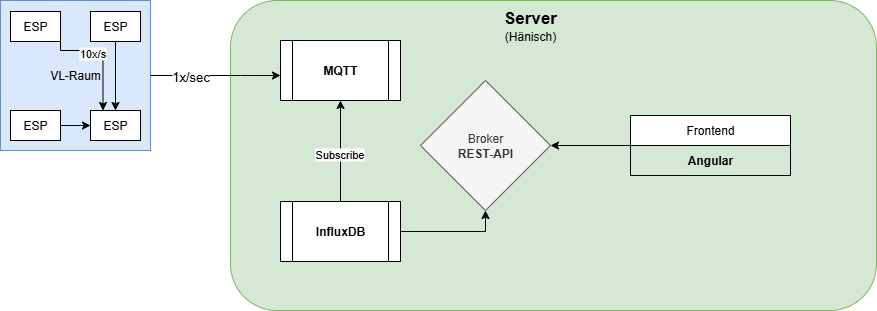
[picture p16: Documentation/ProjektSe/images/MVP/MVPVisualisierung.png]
  
\end{center}

Aufgrundlage des MVPs sollen die folgenden Qualitätsmerkmale sichergestellt werden:
\begin{itemize}
    \item \textbf{Echtheit \& Qualität der Daten:}
    Nur qualitative Daten z.B. durch manuelle Überprüfung und Kalibrierung der Mikrofone ermöglichen realistische Messwerte und damit eine sinnvolle Analyse der akustischen Verhältnisse im Raum.
\item \textbf{Accountability der Daten:}
    Es muss nachvollziehbar sein, welche Sensoren zu welchem Zeitpunkt welche Daten erfasst haben. Diese Anforderung soll durch das Einführen einer eindeutigen ID für jeden Sensor, die mit jedem Value mitgeschickt wird, umgesetzt werden.
    \item \textbf{Verfügbarkeit:}
    Da die Übertragungswege mit ESP-NOW und MQTT unterbrochen werden könnten ist es wichtig die Verfügbarkeit von Daten sicherzustellen indem ein möglicher Ausfall schnellstmöglich erkannt wird um diesen dann beheben zu können. Dies soll sichergestellt werden durch die Einführung einer Notification, die ausgelöst wird beim Ausfall eines Gerätes, was final über einen eigenen Discord-Server bereitgestellt werden soll.
\end{itemize}

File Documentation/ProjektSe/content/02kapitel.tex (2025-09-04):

\begin{landscape}
\chapter{SFMEA-Analyse}
\section{Analyse}
\label{cha:sfmea}
\small
\begin{longtable}{|p{3.4cm}|p{3.4cm}|p{3.4cm}|p{3.4cm}|c|c|c|c|p{3.4cm}|}

    \hline
    \textbf{Systemfunktion} & \textbf{Fehlermöglichkeit} & \textbf{Fehlerursache} & \textbf{Fehlerfolge} & \textbf{B} & \textbf{A} & \textbf{E} & \textbf{RPZ} & \textbf{Maßnahmen} \\
    \hline
    \endhead

    Dezibel erfassen & Falsche oder keine Messwerte & Mikrofon defekt, Sensor ungeeignet & Ungenaue oder keine Daten & 8 & 6 & 3 & 144 & Robuste Mikros, Kalibrierung, Ersatzsensor bereit \\
    \hline
    ESP kommuniziert nicht mit anderen & Keine oder fehlerhafte Datenübertragung & WLAN-Probleme, falsches Protokoll & Daten gehen verloren, keine Heatmap & 7 & 5 & 4 & 140 & Netzwerk prüfen, Fallback, Fehler-Logs \\
    \hline
    Daten werden nicht ans Backend gesendet & ESP schickt keine Daten & Stromausfall, Codecrash, Timeout & Datenlücken, unvollständige Analyse & 7 & 5 & 3 & 105 & Watchdog, Logging, häufigere Syncs \\
    \hline
    GitHub-Zugang fehlerhaft & Kein Zugriff oder Merge-Konflikte & Rechte falsch, keine Git-Strategie & Team kann nicht arbeiten & 6 & 4 & 2 & 48 & Git-Workflow, Rechte regeln \\
    \hline
    Backend speichert keine Daten & Fehlerhafte Speicherung / Absturz & Server voll, Codefehler & Datenverlust, Ausfall & 9 & 4 & 4 & 144 & Monitoring, Logging, Backups, Testlauf \\
    \hline
    Daten werden falsch ausgewertet & Heatmap falsch / Werte inkonsistent & Algorithmusfehler, unvollständige Daten & Falsche Rückschlüsse & 6 & 4 & 3 & 72 & Testdaten prüfen, Algo validieren, Visualisierung testen \\
    \hline
    ESPs messen nicht synchron & Unterschiedliche Messzeitpunkte & Kein Sync, NTP fehlt & Daten nicht vergleichbar & 7 & 5 & 4 & 140 & NTP-Sync, Zeitstempel ergänzen \\
    \hline

\end{longtable}
\end{landscape}

\section{Auswertung}

\begin{itemize}
    \item \textbf{Dezibel erfassen:}
    Während der tatsächlichen Arbeit mit den Sensoren/Mikrofonen trat ein solcher Fehler selten auf, dennoch wurde zur Absicherung beim Ausfall der Sensoren eine Discord-Notifikation hinzugefügt. Deshalb ist die RPZ von 144 grundsätzlich zu hoch.
    \item \textbf{ESP kommuniziert nicht mit anderen:}
    Auch hierbei hilft die bereits genannte Discord-Notifikation. Zusätzlich wurden mehrere Datenübertragungs-Möglichkeiten implementiert und getestet, wobei sich ESP-Now mit einem zusätzlichen Edge-Device, ohne Sensorfunktion, als die beste Option zeigte. Hierdurch wurde das Risiko bestmöglich minimiert. 
    \item \textbf{Daten werden nicht ans Backend gesendet:}
    Wenn Daten nicht am Backend angekommen sind, lag dies meistens an Verbindungsproblemen zwischen den einzelnen Komponenten. Stromausfälle oder Codecrashs waren hierbei quasi nie die Ursache.
    \item \textbf{GitHub-Zugang fehlerhaft:}
    Mit dem Github-Zugang entstanden keine Probleme, jedoch kam es gelegentlich zu Merge-Konflikten, sowie zu kleineren Problemen bei der Zusammenführen der anfangs getrennten Repositories. Daher ist die klein ausfallende RPZ gerechtfertigt.
    \item \textbf{Backend speichert keine Daten:}
    Die hoch angesetzte RPZ wurde durch die Serverprobleme mit dem "Hänisch"-Server und die allgemeine Datenspeicherstruktur des Projekts bestätigt. 
    \item \textbf{Daten werden falsch ausgewertet:}
    Durch die anfängliche Annahme, dass es vorgefertigte Algorithmen/Bibliotheken für unseren Usecase gäbe, wurde die RPZ zu niedrig angesetzt. Da es diese nicht gab, musste der Algorithmus selbst entwickelt werden, was zu einer nicht erwarteten Komplexität führte. Daher ist die RPZ bei mindestens 140 anzusetzen.
    \item \textbf{ESPs messen nicht synchron:}
    Durch das gebündelte Senden der Daten über das Edge-Device und das vereinheitlichen der Daten innerhalb einer Sekunde, entfällt das zwingend genaue Synchronisieren der Messdaten. 
    \item \textbf{Nicht beachtete Störquellen:}
    Ein unerwatetes Problem stellen Störsignale dar, etwa durch das gleichzeitige Senden des Edge-Devices während eigener Sensoraufnahmen, oder durch "laute"  Netzteile anderer Gruppen. Dieses Problem wurde erst spät erkannt und hat sehr viel Zeit in Anspruch genommen, weshalb eine RPZ von 140 angebracht wäre. 
\end{itemize}

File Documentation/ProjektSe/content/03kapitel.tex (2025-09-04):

\chapter{Hardwarekomponenten}

\section{Mikrofonmodule}

Zur Erfassung des Lautstärkepegels wurden drei unterschiedliche Mikrofonmodule in Betracht gezogen. 
Der erste Sensor ist ein kostengünstiges Modul "GY-MAX4466" (ca.\ 4\,€), das ursprünglich als Klatschsensor konzipiert wurde. 
Der zweite Sensor ist das \textit{Sound Level Meter V2.0} von DFRobot (ca.\ 40\,€), das über zusätzliche Hardware zur Signalverarbeitung verfügt und den Schalldruckpegel bereits gefiltert und bereinigt im dBA-Format ausgibt.
Der dritte in Betracht gezogene Sensor ist ein handelsübliches DB-Messgerät (ca.\ 20\,€), das jedoch nicht für die Integration in das Projekt geeignet ist, da es keine digitale Schnittstelle bietet und somit nicht direkt mit dem ESP32 kommunizieren kann.
Dieser Sensor wird daher zur Überprüfung der Ergebnisse verwendet, ist aber nicht für die direkte Integration in das Projekt vorgesehen.

Da die absolute Einheit (dBA) für die Auswertung im Rahmen eines 3D-Diagramms nicht zwingend erforderlich ist, wurde der Fokus auf die Vergleichbarkeit der analogen Ausgangssignale gelegt. 
Beide Sensoren wurden gleichzeitig an einem ESP32 betrieben und ihre Ausgangssignale mithilfe des \textit{Serial Plotter} in Echtzeit visualisiert. 
Dabei zeigte sich, dass die Kurvenverläufe bei normalen Sprachgeräuschen nahezu identisch sind. 
Lediglich bei impulsartigen Geräuschen mit sehr geringer Distanz (z.\,B.\ Klatschen oder Klopfen) erzeugt das günstigere Mikrofon deutlich stärkere Peaks, während diese durch den DFRobot-Sensor wirksam herausgefiltert werden.

\begin{center}
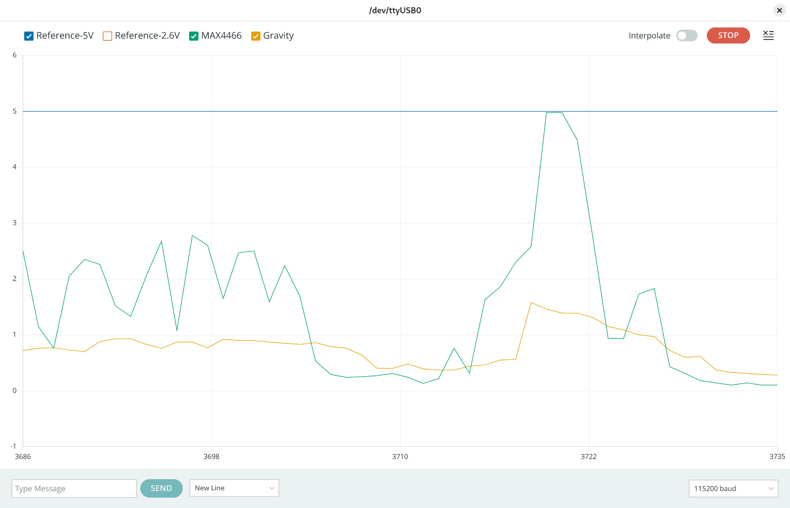
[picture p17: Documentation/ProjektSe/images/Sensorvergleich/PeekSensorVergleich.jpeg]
  
\end{center}
\begin{center}
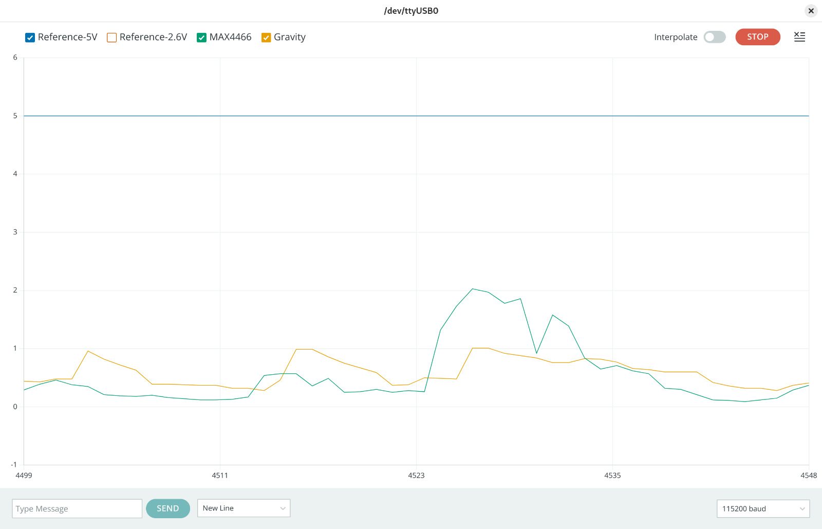
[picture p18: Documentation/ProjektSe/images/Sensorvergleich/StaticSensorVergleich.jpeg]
  
\end{center}

Hier sind die Sensorwerte des günstigeren Klatschsensors (grün), sowie die des Teureren Dba sensors (gelb) dargestellt. Die In Blau dargestellte 5v Referenzlinie stellt den Maximalwert da, welcher von den Sensoren zurückgegeben werden kann.

Da die in den Vergleichsdiagrammen dargestellten Abweichungen bei größerem Abstand deutlich abnehmen und im Anwendungsfall als vernachlässigbar eingestuft werden können, wurde entschieden, den günstigeren Sensor zu verwenden. 
Um mögliche Reststörungen dennoch weiter zu reduzieren, ist geplant, eine mechanische Dämpfung oder Abschirmung am Sensor zu testen.

Insgesamt konnte festgestellt werden, dass der günstigere Sensor trotz fehlender dBA-Ausgabe für die angestrebte Visualisierung ausreichend präzise Ergebnisse liefert und somit für den weiteren Projektverlauf verwendet wird.

\section{ESP32}
Die ESP-Module bieten im Vergleich zu klassischen Arduinos eine integrierte WLAN-Funktionalität und unterstützen direkt das ESP-NOW-Protokoll. Dadurch entfällt zusätzlicher Hardware- oder Softwareaufwand für die Netzwerkkommunikation.
In Kombination mit ESP-NOW ergibt sich somit eine kompakte, performante und zuverlässige Lösung.

\section{Umsetzung}
Nach der Entscheidung für die finalen Hardwarekomponenten wurde dies erfolgreich nach Plan umgesetzt.
Da jedoch das IOT-eigene Netzwerk nicht bis zum lezten ESP im Raum reichte, wurden mehrere Möglichkeiten getestet (WLAN-Repeater, lokaler Access-Point auf Edge-ESP, ESP-Now Brücke).
Final wurde sich für einen fünften ESP entschieden, der nur als Edge-Device fungiert (zuvor war das Edge-Device als Sensor genutzt worden) und die Daten der anderen vier ESPs sammelt und an den MQTT-Server sendet.
Damit waren keine Störgeräusche mehr in den Daten zu finden und die Verbindung war stabil.

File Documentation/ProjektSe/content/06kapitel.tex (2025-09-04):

\chapter{Algorithmus zur Schallquellenlokalisierung}
\label{cha:algorithmus_zur_schallquellenlokalisierung}

In diesem Kapitel werden verschiedene Ansätze zur Lokalisierung einer Schallquelle im Raum beschrieben. Die Verfahren unterscheiden sich in ihrer physikalischen Genauigkeit, im Rechenaufwand sowie in der praktischen Umsetzbarkeit. Es werden sowohl rein mathematische Interpolationsverfahren als auch modellbasierte und lernbasierte Methoden betrachtet.

\section{Grundprinzipien}

Ein präziser, aber aktuell nicht umsetzbarer Ansatz wäre die \textit{Time Difference of Arrival} (TDOA) in Kombination mit Beamforming. Dabei wird die Zeitdifferenz der Schallausbreitung zwischen mehreren Mikrofonen gemessen. Über Verfahren wie Trilateration oder GCC-PHAT lassen sich daraus Einfallswinkel und Quelle berechnen.  
Da die vorhandene Hardware jedoch keine ausreichend genaue Zeitmessung erlaubt, konnte dieser Ansatz bislang nicht praktisch umgesetzt werden.

\section{Betrachtete Verfahren}

\textbf{Bilineare Interpolation:}  
Aus den vier Eckpunkten eines Messrasters wird durch zweifache lineare Interpolation eine flache Ebene gebildet. Dies liefert eine gleichmäßige, symmetrische Heatmap, berücksichtigt jedoch keinerlei physikalische Eigenschaften der Schallausbreitung. Damit eignet sich die Methode eher zur Visualisierung als zur tatsächlichen Lokalisierung.
\begin{lstlisting}[language=JavaScript, caption={Bilineare Interpolation}]
for (let row = 0; row < 10; row++) {
  const y = row / 9;
  const rowData = [];
  for (let col = 0; col < 10; col++) {
    const x = col / 9;
    const V =
      sensorValues.d1 * (1 - x) * (1 - y) +
      sensorValues.d2 * x * (1 - y) +
      sensorValues.d3 * (1 - x) * y +
      sensorValues.d4 * x * y;
    rowData.push(Number(V.toFixed(2)));
  }
  grid.push(rowData);
}
\end{lstlisting}
\begin{minipage}[b]{0.5\textwidth}
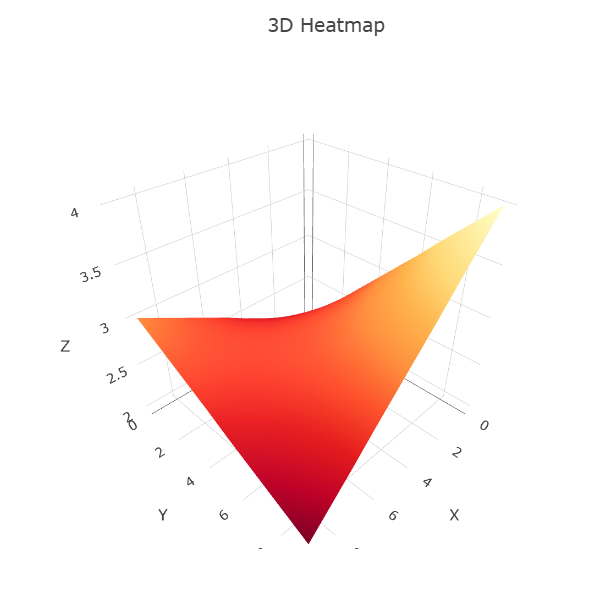
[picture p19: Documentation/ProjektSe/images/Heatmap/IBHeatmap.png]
  
\end{minipage}

\textbf{Inverse Distance Weighting (IDW):}  
Hierbei wird der Einfluss eines Sensors umgekehrt proportional zur Distanz zur betrachteten Position gewichtet, häufig mit einem Distanzexponenten von $p=2$ (inverse quadratische Gewichtung). Das Ergebnis ist eine weiche Heatmap, deren Maximum meist in der Nähe der lautesten Sensoren liegt. Bei mehreren Schallquellen oder komplexer Raumakustik verschwimmt jedoch das Ergebnis.
\begin{lstlisting}[language=JavaScript, caption={Inverse Distance Weighting}]
const power = 2; // Distanzexponent
for (let row = 0; row < 10; row++) {
  const y = row / 9;
  const rowData = [];
  for (let col = 0; col < 10; col++) {
    const x = col / 9;
    let numerator = 0, denominator = 0;
    for (const [key, { x: sx, y: sy }] of Object.entries(sensorPositions)) {
      const value = sensorValues[key];
      const dx = x - sx;
      const dy = y - sy;
      const distance = Math.sqrt(dx * dx + dy * dy) || 0.0001;
      const weight = 1 / Math.pow(distance, power);
      numerator += value * weight;
      denominator += weight;
    }
    rowData.push(Number((numerator / denominator).toFixed(2)));
  }
  grid.push(rowData);
}
\end{lstlisting}
\begin{minipage}[b]{0.5\textwidth}
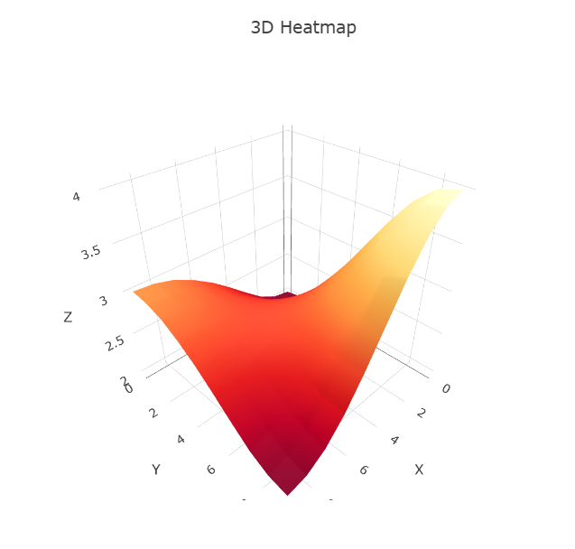
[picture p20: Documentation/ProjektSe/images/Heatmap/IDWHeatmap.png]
  
\end{minipage}

\textbf{Physikalisches Modell – Rückwärtsprojektion:}  
Für jeden Punkt im Raum wird der erwartete Pegel an jedem Mikrofon berechnet:
\[
L = L_0 - 20 \cdot \log_{10}(d)
\]
mit $d$ als Abstand zwischen Quelle und Mikrofon. Anschließend werden die berechneten Werte mit den real gemessenen Pegeln verglichen und die Abweichungen gespeichert. Eine Heatmap zeigt die Positionen mit den geringsten Fehlern als wahrscheinlichste Quelle an.

\textbf{Maximum Likelihood Estimation (MLE):}  
Dieser statistische Ansatz modelliert die Wahrscheinlichkeit, dass eine Quelle an Position $(x, y)$ die gemessenen Pegel $s_i$ erzeugt:
\[
P = \prod_{i=1}^{n} \frac{1}{\sqrt{2\pi\sigma^2}} \cdot
\exp\left(-\frac{(s_i - (L_0 - 20\log_{10} d_i))^2}{2\sigma^2}\right)
\]
Der Punkt mit der höchsten Wahrscheinlichkeit wird als Quellenposition angenommen. Das Verfahren ist robust gegenüber Rauschen, erfordert jedoch ein präzises Modell für Messfehler.

\textbf{Weighted Centroid Localization (WCL):}  
Jeder Sensorwert wirkt wie eine „Gravitationskraft“, die die geschätzte Quelle in seine Richtung zieht. Durch Berechnung des gewichteten Mittelpunkts aller Sensoren lässt sich eine einzelne $(x,y)$-Position bestimmen, die den Schwerpunkt der Schallstärke darstellt. Gut geeignet, wenn ein dominanter Bereich im Raum deutlich lauter ist.
\begin{lstlisting}[language=JavaScript, caption={Weighted Centroid Localization (WCL)}]
	power = 2;    
  for (const [key, { x, y }] of Object.entries(sensorPositions)) {
    const value = sensorValues[key];
    const weight = Math.pow(value, power);
    weightedX += x * weight;
    weightedY += y * weight;
    weightSum += weight;
  }
\end{lstlisting}
\begin{minipage}[b]{0.5\textwidth}
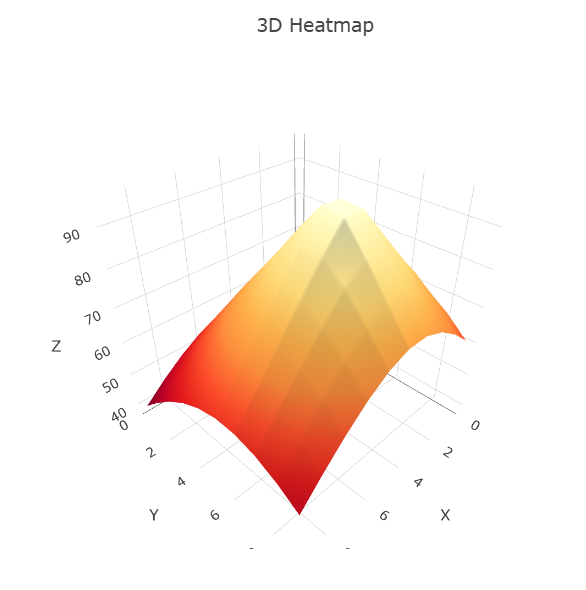
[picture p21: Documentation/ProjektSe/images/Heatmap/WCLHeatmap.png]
  
\end{minipage}

\textbf{Machine Learning:}  
Durch Training eines Modells (z. B. KNN, Random Forest, MLP) mit bekannten Quellenpositionen und zugehörigen Pegelwerten kann die Quellenposition direkt aus den Messwerten vorhergesagt werden. Bei guter Trainingsbasis liefert dies sehr schnelle und präzise Ergebnisse. Allerdings sind umfangreiche und repräsentative Trainingsdaten erforderlich.

\textbf{Kombinierter IDW-WCL-Ansatz:}  
Zur Verbesserung der Lokalisierungsgenauigkeit wird zunächst eine IDW-Heatmap berechnet. Anschließend wird der durch WCL ermittelte Schwerpunkt durch einen zusätzlichen Peak (z. B. Gauß-Blob) verstärkt und in die Heatmap eingeblendet. Dadurch lassen sich weiche Verteilungen mit einem klaren Maximum kombinieren.
\begin{lstlisting}[language=JavaScript, caption={Kombinierter IDW-WCL-Ansatz}]
    for (let row = 0; row < gridSize; row++) {
      const y = row / (gridSize - 1);
      const rowData = [];

      for (let col = 0; col < gridSize; col++) {
        const x = col / (gridSize - 1);
        let numerator = 0;
        let denominator = 0;

        for (const point of interpolationPoints) {
          const dx = x - point.x;
          const dy = y - point.y;
          const distance = Math.sqrt(dx * dx + dy * dy) || epsilon;
          const weight = 1 / Math.pow(distance, idwFlatteningPower);
          numerator += point.value * weight;
          denominator += weight;
        }

        const interpolatedValue = numerator / denominator;
        rowData.push(Number(interpolatedValue.toFixed(2)));
      }

      grid.push(rowData);
    }
\end{lstlisting}
\begin{minipage}[b]{0.5\textwidth}
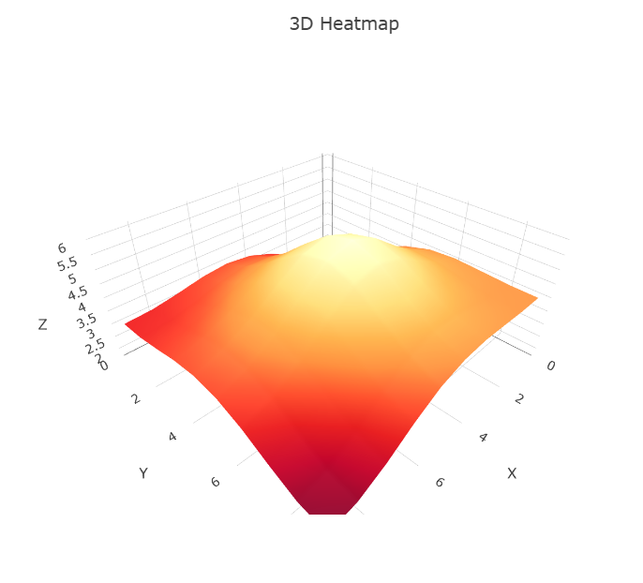
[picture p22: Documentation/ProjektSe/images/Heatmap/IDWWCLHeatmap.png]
  
\end{minipage}

\section{Vergleich der Verfahren}

\begin{center}
\renewcommand{\arraystretch}{1.2}
\begin{adjustbox}{max width=\textwidth}
\begin{tabular}{|l|l|p{3cm}|p{3cm}|p{2.3cm}|}
\hline
\textbf{Methode} & \textbf{Typ} & \textbf{Vorteile} & \textbf{Nachteile} & \textbf{Quelle bestimmbar?} \\
\hline
Bilineare Interpolation & Interpolation & Schnell, symmetrische Heatmap & Kein physikalischer Bezug & Ungefähr \\
\hline
IDW & Interpolation & Einfach, intuitiv, glatte Heatmap & Kein klares Maximum & Ungefähr \\
\hline
Physikalisches Modell & Modellbasiert & Realitätsnah & Rechenintensiv, Annahmen nötig & Ja (Heatmap) \\
\hline
MLE & Wahrscheinlichkeit & Robust, statistisch fundiert & Modell für Fehler nötig & Ja (Wahrscheinlichkeit) \\
\hline
WCL & Schätzwert & Einfach, schneller Indikator & Ungenau bei asymmetrischen Verteilungen & Ja (Koordinate) \\
\hline
Machine Learning & Lernbasiert & Sehr schnell nach Training & Trainingsdaten nötig & Ja (xy direkt) \\
\hline
\end{tabular}
\end{adjustbox}
\end{center}

\section{Fazit}

Aus den Tests ergeben sich folgende Tendenzen:  
\begin{itemize}
    \item \textbf{Machine Learning} liefert bei guter Umsetzung die besten Ergebnisse, ist jedoch mit hohem Initialaufwand verbunden.
    \item \textbf{WCL} eignet sich gut, um den ungefähren Lautstärkenschwerpunkt im Raum zu bestimmen.
    \item \textbf{IDW} ist hilfreich, um Unterschiede in der Schallverteilung („hinten lauter als vorne“) darzustellen.
    \item \textbf{MLE} bietet hohes Potenzial für präzise Ortung, ist jedoch rechenintensiv und komplex in der Parametrisierung.
\end{itemize}

Eine Kombination aus IDW und WCL hat sich als vielversprechend erwiesen, um eine aussagekräftige Heatmap mit einem klar erkennbaren Maximum zu erzeugen.
Zudem ist diese Methode relativ einfach zu implementieren und benötigt keine aufwändige Kalibrierung.
Die Heatmap wird mit aktuellen Daten getestet, somit kann der Algorythmus durch die gewichtung von IDW und WCL angepasst werden.

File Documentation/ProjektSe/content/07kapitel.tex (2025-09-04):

\chapter{API-Kommunikation}
\label{cha:api_kommunikation}
In diesem Kapitel wird die Kommunikation zwischen Frontend und Backend beschrieben, insbesondere die Übertragung von Heatmap-Daten. Es werden verschiedene Ansätze zur Datenübertragung und -kompression vorgestellt, um die Effizienz und Performance der Anwendung zu optimieren.
\section{Problemstellung}
Wenn für jede Slider-Position eine API-Abfrage durchgeführt wird:
\begin{itemize}
    \item Bei einer Frequenz von 10~Hz (alle 100\,ms ein Datenpaket) ergeben sich 36{,}000 Zeitpunkte pro Sensor und somit 144{,}000 Werte pro Stunde.
    \item Beispielrechnung: $36{,}000 \times 10 \times 10 = 3{,}6$~Millionen Werte für ein $10\times10$-Array.
\end{itemize}

\section{Datenbasis}
\begin{itemize}
    \item \textbf{Heatmap-Größe:} $10\times10$ Werte (100 Felder pro Heatmap)
    \item \textbf{Datentyp:} Float16 (2~Byte pro Wert)
    \item \textbf{Frequenz:} 10~Hz (alle 100\,ms ein Frame)
    \item \textbf{Beispiel:} 1 Stunde = 3{,}600 Sekunden = 36{,}000 Frames
\end{itemize}

\noindent\textbf{Speicherbedarf (unkomprimiert):}
\[
100 \cdot 2\ \text{Bytes} = 200\ \text{Bytes/Frame}
\]
\[
200 \cdot 36{,}000 = 7{,}200{,}000\ \text{Bytes} \approx 7.2\ \text{MB}
\]

\section{Optimierungsoptionen}
\begin{enumerate}
    \item \textbf{Downsampling (Mittelwert pro Sekunde)} \\
    3{,}600 Frames/h → $3{,}600 \times 100$ Werte = 0.72\,MB.  
    Vorteil: geringe Datenmenge, einfaches JSON; Nachteil: Peaks nicht sichtbar.
    \item \textbf{Textkompression (Gzip/Brotli)} \\
    Reduktion auf ca. 15–25\,\% → $\approx 1.8$\,MB.
    \item \textbf{Binärformate (MessagePack, Protobuf, FlatBuffers)} \\
    30–40\,\% Ersparnis gegenüber JSON → $\approx 5.0$\,MB.
    \item \textbf{Binär + Kompression} \\
    Kombination aus beidem → $\approx 1.2$\,MB.
    \item \textbf{Delta-Encoding (nur Änderungen)} \\
    Angenommen: jeder 3.~Wert ändert sich → $\approx 3.4$\,MB.
    \item \textbf{Delta-Encoding + Kompression} \\
    Weitere Reduktion auf $\approx 1.0$–$1.2$\,MB.
    \item \textbf{Pre-Exportierte Dateien} \\
    Backend exportiert pro Stunde eine Datei → $\approx 7.2$\,MB.
    \item \textbf{Pre-Export + Kompression} \\
    Speicherbedarf: $\approx 1.2$\,MB/h; sehr performant und cachebar.
\end{enumerate}

\section{Vergleich der Ansätze}

\begin{center}
\begin{adjustbox}{max width=\textwidth}
\begin{tabular}{|l|c|p{5cm}|p{5cm}|}
\hline
\textbf{Beschreibung} & \textbf{Speicher/h} & \textbf{Vorteile} & \textbf{Nachteile} \\ \hline
Mittelwert pro Sekunde (Downsampling) & $\approx 0.72$\,MB & Sehr leicht, JSON möglich, wenig Traffic & Daten stark geglättet, Peaks nicht sichtbar \\ \hline
JSON + Gzip/Brotli & $\approx 1.8$\,MB & Einfach umsetzbar, keine großen Änderungen & Höhere Lesezeit, trotzdem noch Textformat \\ \hline
Binärformat & $\approx 5.0$\,MB & Schnell zu dekodieren, weniger Overhead & Komplexere Integration im Frontend \\ \hline
Binär + Kompression & $\approx 1.2$\,MB & Gute Mischung aus Effizienz \& Geschwindigkeit & Backend-Implementierung aufwändiger \\ \hline
Delta-Encoding & $\approx 3.5$\,MB & Ideal bei geringen Änderungen & Schlecht bei stark variablen Daten \\ \hline
Delta + Kompression & $1.0$–$1.2$\,MB & Sehr gute Kompression & Schwer zu debuggen, komplex \\ \hline
Pre-Export (roh) & $\approx 7.2$\,MB & Kein Runtime-Rechenaufwand, einfaches Caching & Hoher Speicherbedarf \\ \hline
Pre-Export + Kompression & $\approx 1.2$\,MB & Sehr performant, cachebar, ideal für Slider & Dateiverwaltung nötig \\ \hline
\end{tabular}
\end{adjustbox}
\end{center}

\section*{Fazit}
Aufgrund der hohen Komplexität und der großen Datenmengen ist es sinnvoll, die Heatmap-Arrays in einer separaten Datenbasis zu speichern. 
Das Frontend erhält die Daten in vorverarbeiteter Form durch Downsampling, um die Übertragungsmenge zu reduzieren und die Darstellungsgeschwindigkeit zu erhöhen. 
Zusätzlich wird eine Komprimierung der Daten in Betracht gezogen, um den Speicher- und Bandbreitenbedarf weiter zu minimieren, ohne die wesentliche Aussagekraft der Werte zu verlieren.

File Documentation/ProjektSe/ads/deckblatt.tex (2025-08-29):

%!TEX root = ../dokumentation.tex

\begin{titlepage}
	\begin{longtable}{p{.4\textwidth} p{.4\textwidth}}
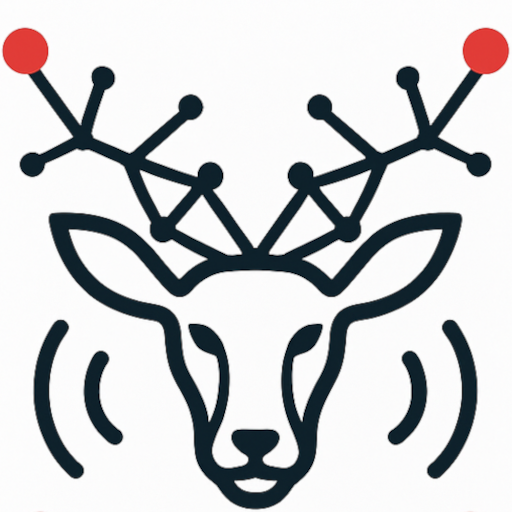
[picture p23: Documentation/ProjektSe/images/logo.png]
	  {} & 
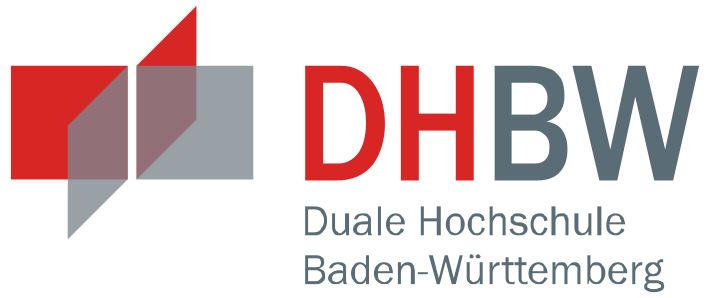
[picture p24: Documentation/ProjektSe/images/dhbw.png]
	  {}
	\end{longtable}
	\enlargethispage{20mm}
	\begin{center}
	\vspace*{12mm}	{\LARGE\bf \titel }\\
    \vspace*{12mm} SE-Projekt\\
    \vspace*{3mm} des Studiengangs\\
    \vspace*{3mm} Allgemeine Informatik\\
    \vspace*{12mm} an der Dualen Hochschule Baden-Württemberg, Campus Heidenheim\\
	  %\vspace*{12mm}	{\large\bf \arbeit}\\
	  %\vspace*{12mm}	für die Prüfung zum\\
	  %\vspace*{3mm} 	{\bf \abschluss}\\
	  %\vspace*{12mm}	des \studiengang\\
	  %\vspace*{3mm} 	an der Dualen Hochschule Baden-Württemberg \dhbw\\
	  %\vspace*{12mm}	von\\
	  %\vspace*{3mm} 	{\large\bf \autor}\\
	  %\vspace*{12mm}	\datumAbgabe\\
	  \begin{center}
  \textit{Diese Dokumentation entstand im Rahmen des Software-Engineering-Projekts 
  an der Dualen Hochschule Baden-Württemberg. 
  Sie beschreibt die Konzeption und Umsetzung von AudiTim, einem verteilten System zur akustischen Raumüberwachung, 
  dessen Ziel die Erfassung, Speicherung und Visualisierung von Lautstärkedaten in einem Vorlesungsraum ist.}
\end{center}
	\end{center}
	\vfill
	\begin{spacing}{1.2}
	\begin{tabbing}
		mmmmmmmmmmmmmmmmmmmmmmmmmm     \= \kill
		\textbf{Bearbeitungszeitraum}  \>  \zeitraum\\
		\textbf{Gruppe, Kurs}  \>  \martrikelnr, \kurs\\
		\textbf{Gruppenmitglieder}      \>  \firma\\
		\textbf{}              \>  \betreuer\\
		%\textbf{Gutachter}             \>  \gutachter
	\end{tabbing}
	\end{spacing}
\end{titlepage}

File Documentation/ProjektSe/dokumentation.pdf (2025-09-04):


## AudiTim Dokumentation

SE-Projekt

des Studiengangs

Allgemeine Informatik

an der Dualen Hochschule Baden-Württemberg, Campus Heidenheim

Diese Dokumentation entstand im Rahmen des Software-Engineering-Projekts an der Dualen Hochschule Baden-Württemberg. Sie beschreibt die Konzeption und Umsetzung von AudiTim, einem verteilten System zur akustischen Raumüberwachung, dessen Ziel die Erfassung, Speicherung und Visualisierung von Lautstärkedaten in einem Vorlesungsraum ist.

Bearbeitungszeitraum | 10 Wochen
Gruppe, Kurs | 5, INF2023AI
Gruppenmitglieder | Aaron Reiber, Jan-David Oberländer,
| Luca Müller, Moritz Flaig

# Inhaltsverzeichnis

1 Einleitung | 1
2 SFMEA-Analyse | 4
3 Hardwarekomponenten | 8
4 Softwarekomponenten | 11
5 Befestigung der Hardware | 21
6 Algorithmus zur Schallquellenlokalisierung | 27

I

7 API-Kommunikation | 35
Literaturverzeichnis | i

II

# 1 Einleitung

Im Rahmen des Software-Engineering-Projekts wird in einem Team ein System zur akustischen Raumüberwachung entwickelt. Ziel des Projekts ist die kontinuierliche Erfassung und spätere Analyse der Lautstärkeverteilung in einem typischen Vorlesungsraum über den Zeitraum mehrerer Tage hinweg.

## 1.1 Projektüberblick

Die Umsetzung erfolgt nach agilen Prinzipien unter Anwendung von Scrum, wobei die jeweiligen Sprints von Freitag bis Freitag festgelegt wurden.

Die technische Architektur sieht den Einsatz von vier Mikrocontroller-Einheiten (ESP32) vor, die jeweils mit einem Mikrofon oder einem Dezibel-Messsensor ausgestattet werden. Die Geräte werden in den vier Ecken des Vorlesungsraums positioniert, um eine möglichst flächendeckende Abdeckung des Raumes zu gewährleisten. Über ein Kommunikationsprotokoll tauschen sich die ESPs untereinander aus und senden die gesammelten Messdaten gemeinsam an ein zentrales Backend.

## 1.2 Ziele und Motivation

Ziel ist es, ein skalierbares und robustes System zu entwickeln, das Lautstärkepegel über einen längeren Zeitraum erfassen kann. Die gesammelten Daten sollen im Backend gespeichert und im Nachgang analysiert werden. Hierbei sind verschiedene Darstellungsformen wie etwa Heatmaps oder zeitbasierte Diagramme denkbar, um Muster oder Auffälligkeiten im akustischen Verhalten des Raumes sichtbar zu machen.

1

## 1.3 MVP und Qualitätsmerkmale

Im Rahmen des MVPs soll ein verteiltes System zur akustischen Raumüberwachung auf Basis von vier Mikrocontrollern der ESP-Serie entwickelt werden. Jeder ESP wird über ein extern angeschlossenes Mikrofon verfügen, mit dem kontinuierlich Lautstärkedaten erfasst werden. Drei der Module sollen ihre Messwerte mithilfe des ESP-NOW-Protokolls an eine zentrale Einheit übermitteln, die zusätzlich eigene Daten erfasst. Die aggregierten Informationen aller vier Einheiten werden in festen Intervallen über das MQTT-Protokoll an einen Server gesendet und dort zeitsynchron in einer InfluxDB gespeichert. Über eine REST-API sollen die Daten einem Angular-basierten Web-Frontend zur Visualisierung der akustischen Messwerte zur Verfügung gestellt werden.


Aufgrundlage des MVPs sollen die folgenden Qualitätsmerkmale sichergestellt werden:

- Echtheit & Qualität der Daten: Nur qualitative Daten z.B. durch manuelle Überprüfung und Kalibrierung der Mikrofone ermöglichen realistische Messwerte und damit eine sinnvolle Analyse der akustischen Verhältnisse im Raum.
- Accountability der Daten: Es muss nachvollziehbar sein, welche Sensoren zu welchem Zeitpunkt welche Daten erfasst haben. Diese Anforderung soll durch das Einführen einer eindeutigen ID für jeden Sensor, die mit jedem Value mitgeschickt wird, umgesetzt werden.
- Verfügbarkeit: Da die Übertragungswege mit ESP-NOW und MQTT unterbrochen werden könnten ist es wichtig die Verfügbarkeit von Daten sicherzustellen indem ein möglicher Ausfall schnellstmöglich erkannt wird um diesen dann

2

beheben zu können. Dies soll sichergestellt werden durch die Einführung einer Notification, die ausgelöst wird beim Ausfall eines Gerätes, was final über einen eigenen Discord-Server bereitgestellt werden soll.

3

# 2 SFMEA-Analyse

## 2.1 Analyse

Systemfunktion | Fehlermöglichkeit | Fehlerursache | Fehlerfolge | B | A | E | RPZ | Maßnahmen
Dezibel erfassen | Falsche oder keine Messwerte | Mikrofon defekt, Sensor ungeeignet | Ungenaue oder kei-ne Daten | 8 | 6 | 3 | 144 | Robuste Mikros, Kalibrierung, Er-satzsensor bereit
ESP kommuniziert nicht mit anderen | Keine oder fehler-gung hafte Datenübertra- | WLAN-Probleme, falsches Protokoll | Daten gehen verlo- ren, keine Heatmap | 7 | 5 | 4 | 140 | Netzwerk prüfen, Fallback, Fehler- Logs
Daten werden nicht ans Backend gesen-det | ESP schickt keine Daten | Stromausfall, Code-crash, Timeout | Datenlücken, unvollständige Analyse | 7 | 5 | 3 | 105 | Watchdog, Logging, häufigere Syncs
GitHub-Zugang feh-lerhaft | Kein Zugriff oder Merge-Konflikte | Rechte falsch, keine Git-Strategie | Team kann nicht ar- beiten | 6 | 4 | 2 | 48 | Git-Workflow, Rech- te regeln

4

Systemfunktion | Fehlermöglichkeit | Fehlerursache | Fehlerfolge | B | A | E | RPZ | Maßnahmen
Backend speichert keine Daten | Fehlerhafte Speiche-rung / Absturz | Server voll, Code- fehler | Datenverlust, Aus- fall | 9 | 4 | 4 | 144 | Monitoring, Backups, Log- ging, Testlauf
Daten werden falsch ausgewertet | Heatmap falsch / Werte inkonsistent | Algorithmusfehler, unvollständige Daten | Falsche Rückschlüs-se | 6 | 4 | 3 | 72 | Testdaten validieren, prüfen, Algo Visualisierung testen
ESPs messen nicht synchron | Unterschiedliche Messzeitpunkte | Kein Sync, NTP fehlt | Daten nicht ver-gleichbar | 7 | 5 | 4 | 140 | NTP-Sync, Zeitstem- pel ergänzen

5

## 2.2 Auswertung

- Dezibel erfassen: Während der tatsächlichen Arbeit mit den Sensoren/Mikrofonen trat ein solcher Fehler selten auf, dennoch wurde zur Absicherung beim Ausfall der Sensoren eine Discord-Notifikation hinzugefügt. Deshalb ist die RPZ von 144 grundsätzlich zu hoch.
- ESP kommuniziert nicht mit anderen: Auch hierbei hilft die bereits genannte Discord-Notifikation. Zusätzlich wurden mehrere Datenübertragungs-Möglichkeiten implementiert und getestet, wobei sich ESP-Now mit einem zusätzlichen Edge-Device, ohne Sensorfunktion, als die beste Option zeigte. Hierdurch wurde das Risiko bestmöglich minimiert.
- Daten werden nicht ans Backend gesendet: Wenn Daten nicht am Backend angekommen sind, lag dies meistens an Verbindungsproblemen zwischen den einzelnen Komponenten. Stromausfälle oder Codecrashs waren hierbei quasi nie die Ursache.
- GitHub-Zugang fehlerhaft: Mit dem Github-Zugang entstanden keine Probleme, jedoch kam es gelegentlich zu Merge-Konflikten, sowie zu kleineren Problemen bei der Zusammenführen der anfangs getrennten Repositories. Daher ist die klein ausfallende RPZ gerechtfertigt.
- Backend speichert keine Daten: Die hoch angesetzte RPZ wurde durch die Serverprobleme mit dem "HänischServer und die allgemeine Datenspeicherstruktur des Projekts bestätigt.
- Daten werden falsch ausgewertet: Durch die anfängliche Annahme, dass es vorgefertigte Algorithmen/Bibliotheken für unseren Usecase gäbe, wurde die RPZ zu niedrig angesetzt. Da es diese nicht gab, musste der Algorithmus selbst entwickelt werden, was zu einer nicht erwarteten Komplexität führte. Daher ist die RPZ bei mindestens 140 anzusetzen.
- ESPs messen nicht synchron: Durch das gebündelte Senden der Daten über das Edge-Device und das vereinheitlichen der Daten innerhalb einer Sekunde, entfällt das zwingend genaue Synchronisieren der Messdaten.

6

- Nicht beachtete Störquellen: Ein unerwatetes Problem stellen Störsignale dar, etwa durch das gleichzeitige Senden des Edge-Devices während eigener Sensoraufnahmen, oder durch "laute"Netzteile anderer Gruppen. Dieses Problem wurde erst spät erkannt und hat sehr viel Zeit in Anspruch genommen, weshalb eine RPZ von 140 angebracht wäre.

7

# 3 Hardwarekomponenten

## 3.1 Mikrofonmodule

Zur Erfassung des Lautstärkepegels wurden drei unterschiedliche Mikrofonmodule in Betracht gezogen. Der erste Sensor ist ein kostengünstiges Modul "GY-MAX4466"(ca. 4 €), das ursprünglich als Klatschsensor konzipiert wurde. Der zweite Sensor ist das Sound Level Meter V2.0 von DFRobot (ca. 40 €), das über zusätzliche Hardware zur Signalverarbeitung verfügt und den Schalldruckpegel bereits gefiltert und bereinigt im dBA-Format ausgibt. Der dritte in Betracht gezogene Sensor ist ein handelsübliches DB-Messgerät (ca. 20 €), das jedoch nicht für die Integration in das Projekt geeignet ist, da es keine digitale Schnittstelle bietet und somit nicht direkt mit dem ESP32 kommunizieren kann. Dieser Sensor wird daher zur Überprüfung der Ergebnisse verwendet, ist aber nicht für die direkte Integration in das Projekt vorgesehen.

Da die absolute Einheit (dBA) für die Auswertung im Rahmen eines 3D-Diagramms nicht zwingend erforderlich ist, wurde der Fokus auf die Vergleichbarkeit der analogen Ausgangssignale gelegt. Beide Sensoren wurden gleichzeitig an einem ESP32 betrieben und ihre Ausgangssignale mithilfe des Serial Plotter in Echtzeit visualisiert. Dabei zeigte sich, dass die Kurvenverläufe bei normalen Sprachgeräuschen nahezu identisch sind. Lediglich bei impulsartigen Geräuschen mit sehr geringer Distanz (z. B. Klatschen oder Klopfen) erzeugt das günstigere Mikrofon deutlich stärkere Peaks, während diese durch den DFRobot-Sensor wirksam herausgefiltert werden.

8


9

Hier sind die Sensorwerte des günstigeren Klatschsensors (grün), sowie die des Teureren Dba sensors (gelb) dargestellt. Die In Blau dargestellte 5v Referenzlinie stellt den Maximalwert da, welcher von den Sensoren zurückgegeben werden kann.

Da die in den Vergleichsdiagrammen dargestellten Abweichungen bei größerem Abstand deutlich abnehmen und im Anwendungsfall als vernachlässigbar eingestuft werden können, wurde entschieden, den günstigeren Sensor zu verwenden. Um mögliche Reststörungen dennoch weiter zu reduzieren, ist geplant, eine mechanische Dämpfung oder Abschirmung am Sensor zu testen.

Insgesamt konnte festgestellt werden, dass der günstigere Sensor trotz fehlender dBA-Ausgabe für die angestrebte Visualisierung ausreichend präzise Ergebnisse liefert und somit für den weiteren Projektverlauf verwendet wird.

## 3.2 ESP32

Die ESP-Module bieten im Vergleich zu klassischen Arduinos eine integrierte WLAN-Funktionalität und unterstützen direkt das ESP-NOW-Protokoll. Dadurch entfällt zusätzlicher Hardware- oder Softwareaufwand für die Netzwerkkommunikation. In Kombination mit ESP-NOW ergibt sich somit eine kompakte, performante und zuverlässige Lösung.

## 3.3 Umsetzung

Nach der Entscheidung für die finalen Hardwarekomponenten wurde dies erfolgreich nach Plan umgesetzt. Da jedoch das IOT-eigene Netzwerk nicht bis zum lezten ESP im Raum reichte, wurden mehrere Möglichkeiten getestet (WLAN-Repeater, lokaler Access-Point auf Edge-ESP, ESP-Now Brücke). Final wurde sich für einen fünften ESP entschieden, der nur als Edge-Device fungiert (zuvor war das Edge-Device als Sensor genutzt worden) und die Daten der anderen vier ESPs sammelt und an den MQTT-Server sendet. Damit waren keine Störgeräusche mehr in den Daten zu finden und die Verbindung war stabil.

10

# 4 Softwarekomponenten

## 4.1 Entwicklungsumgebungen

Zu Beginn des Projekts wurden zwei gängige Entwicklungsumgebungen für die Programmierung von Mikrocontrollern evaluiert: die klassische Arduino IDE, welche auch von den betreuenden Dozierenden empfohlen wurde, sowie die moderne, zunehmend verbreitete PlatformIO-Erweiterung für Visual Studio Code. Im Projektteam wird plattformübergreifend mit Linux, Windows 10 und Windows 11 gearbeitet. Beide Entwicklungsumgebungen sind grundsätzlich mit allen eingesetzten Betriebssystemen kompatibel. Zur Prüfung der technischen Umsetzbarkeit wurden zwei separate Repositories eingerichtet, in denen jeweils einfache Testprojekte zur Ansteuerung eines ESP32 implementiert wurden. Beide IDEs konnten den Mikrocontroller erfolgreich ansprechen. PlatformIO bietet durch seine deklarative Verwaltung von Bibliotheken und Abhängigkeiten Vorteile in Bezug auf Reproduzierbarkeit und Build-Konsistenz. In der Praxis kam es jedoch auf einem System im Team zu anhaltenden technischen Problemen mit PlatformIO, die nicht zufriedenstellend gelöst werden konnten. Um eine einheitliche und zuverlässige Entwicklungsgrundlage für alle Teammitglieder sicherzustellen, fiel die Entscheidung letztlich zugunsten der Arduino IDE. Diese ermöglicht eine barrierefreie Mitarbeit aller Beteiligten, auch wenn sie im Funktionsumfang nicht ganz an PlatformIO heranreicht.

## 4.2 Kommunikationsmethode

ESP-NOW wurde ausgewählt, da es im Vergleich zu anderen Protokollen einen deutlich geringeren Overhead besitzt und dadurch eine schnellere und effizientere Datenübertragung ermöglicht. Die Struktur ist weniger komplex, was die Implementierung vereinfacht und die Fehleranfälligkeit reduziert. Dadurch wird das System insgesamt

11 robuster und zuverlässiger: ESP-Now ist ein Kommunikationsprotokoll von Espressif, das speziell für die ESP32- und ESP8266-Chips entwickelt wurde. Es verwendet die 2,4 Ghz Frequenz, welche eigentlich für WiFi Kommunikation verwendet wird. Im Gegensatz zu anderen Protokollen sind die Nachrichten auf Schicht 2 des ISO-OSI-Modells. Keine IP-Adressen sondern nur MAC-Adressen. Die ESPs müssen sich dafür im gleichen Kanal befinden. Die 2,4 Ghz Frequenz hat grundsätzlich nur 3 Nutzbare Kanäle. Der zu verwendene Kanal muss von dem ÄI401"Wlan Netz übernommen werden.Es ist mit relativ wenig Code möglich eine große Menge an Daten in sehr Kurzen Zeitabschnitten zu senden. Theoretisch ist eine Datenübertragung von 1 bis 2 Mbps möglich. Die Nachrichtenlänge ist auf 250 Byte pro Paket beschränkt. Da unsere Nachrichten nur wenige Bit lang sind, haben wir hier keine Probleme. Das Protokoll hat keine festgelegten Sender/Empfänger Rollen. Jeder ESP kann senden und empfangen. In unserem Beispiel senden aber 3 ESPs und ein Edge-Device empfängt alle Daten. Es wird 10 mal pro Sekunde der Lautstärkepegel erfasst und gesendet.

## 4.3 Frontend

### 4.3.1 Technologieauswahl

Für die Umsetzung des Frontends wurde das Framework Angular gewählt. Diese netschiedung basiert auf technischen Faktoren und persönlichen Preferenzen. Angular bietet eine klare Struktur durch komponentenbasiertes Design und ist für die moderne Webentwicklung gut geeignet. Es erleichtert die Wiederverwendbarkeit von eigenen aber auch externen UI-Elementen und unterstützt eine saubere Trennung von Logik und Darstellung.

Im Vergleich dazu ist React ein von Meta entwickeltes UI-Framework. Angular und React haben beide eine komponentenbasierte Architektur. Diese Komponenten sind innerhalb anderer Komponenten wiederverwendbar und somit endlos wiederverwertbar. Beide sind Open Source. Daher haben React und Angular große Entwicklergemeinschaften, die die Ressourcen regelmäßig erweitern. Angular ist ein vollwertiges Framework, während React eine JavaScript-Bibliothek ist. Deshalb muss React mit einem Framework gepaart werden, um eine schnelle, schöne und kompatible Benutzeroberfläche zu erstellen. (Powell, 2023)

12

Da außerdem im Team bereits umfangreiche Erfahrung mit diesem Framework vorhanden war, fiel die Entscheidung zugunsten von Angular. Das Frontend läuft in einem eigenen Docker-Container und kommuniziert, über ein internes Netzwerk, mit dem separat laufenden Backend-Container. So bleibt die Architektur modular, skalierbar und einfach wartbar.

### 4.3.2 Umsetzungsplan

Während der Entwicklung wurde ein einfaches Frontend zu Testzwecken angelegt. Deshalb soll nun ein Plan entwickelt werden, wie die Benutzeroberfläche aussehen soll und welche Funktionen sie bieten soll:


In dieser Skizze wurden die Grundfunktionen der Benutzeroberfläche festgelegt und die Anordnung der einzelnen Elemente skizziert. Über eine Navbar an der linken Seite kann zwischen den einzelnen Seiten gewechselt werden. Auf der Hauptseite wird eine Heatmap angezeigt, die die Lautstärkeverteiung im Vorlesungsraum räumlich darstellt, wobei mit einem Dropdown-Menü der anzuzueigende Zeitraum ausgewählt werden kann. Durch den ausgewählten Zeitraum kann anschließend mit einem Schieberegler die Zeit ausgewählt werden, für die die Lautstärke angezeigt werden soll. Im nächsten Nav-Item sollen die einzelnen 2D-Grafen der jeweiligen Sensoren angezeigt werden.

13

Das dritte Nav-Item soll einen tabellarischen Überblick über die gesammelten Daten geben, die in der Datenbank gespeichert sind. Die Nvabar bietet Raum für zukünfitge Erweiterungen.

### 4.3.3 Umsetzung

Auf Grundlage dieser Skizze wurde das Frontend und UI efolgreich umgesetzt. So hat man nun eine übersichtliche Homepage, die auf alle Elemente verweist, welche auch in der interaktiven Navbar zu finden sind. Als kleines AddOn wurde unteranderem hierfür ein ÄudiTim"Logo entworfen, was den ikonischen Hirsch mit dem vernetzten Geweih und den Audiowellen verknüpft, sowie eine Light- und Darkmode Funktionalität implementiert.


Auch im Screenshot zu sehen, sind die schlussendlich umgesetzten Seiten; Heatmap, 2D-Sensoren, Peakmap, Github Repo, Dokumentation und Admin. Für diese Seiten wurden die in der Skizze angedachten Funktionen erfolgreich umgesetzt und flexibel während der Entwicklung angepasst und erweitert.

So zeigt die Admin-Seite nun eine Übersicht über die verbundenen Container und Elemte sowie deren Status an:

14


Die 2D-Sensoren-Seite zeigt die einzelnen Sensorwerte in übersichtlichen Liniendiagrammen an, wobei man zwischen einem ausgewählten Zeitraum und einem Live-Modus wechseln kann:


Auch die Heatmap-Seite zeigt die Auswahl zwischen einem ausgewählten Zeitraum und einem Live-Modus, sowie einen Average-Modus, in dem die durchschnittliche Lautstärke über den ausgewählten Zeitraum angezeigt wird. Mit einem Schieberegler kann die Zeit innerhalb des ausgewählten Zeitraums angepasst werden und gegenenenfalls eine Animation gestartet werden, die die Lautstärkeverteilung über den Zeitraum hinweg anzeigt. Außerdem wurde das in "4.5 3D-Raummodellierung"beschriebene 3D-Modell des Raumes als Hintergrundbild für die Heatmap verwendet, um eine realistische Darstellung zu ermöglichen:

15


Dieses 3D-Modell wurde auch für die Peakmap-Seite verwendet, auf der die Spitzenwerte der Sensoren über den ausgewählten Zeitraum angezeigt werden:

Und zu guter Letzt zeigt die Dokumentation-Seite diese Dokumentation, die sie hier gerade lesen, in einem eingebetteten PDF-Viewer an.

16

### 4.3.4 Testing

Für die Umsetzung des automatisierten Testings wurde Playwright eingesetzt. Die Auswahl dieses Frameworks erfolgte nach einer vergleichenden Analyse. Dabei wurde Playwright von einem Teammitglied im Rahmen einer Projektarbeit mit einem ähnlichen Anwendungsfall ausführlich evaluiert und als am geeignetsten bewertet. Ausschlaggebend hierfür waren insbesondere die breite Browserunterstützung, die integrierten Funktionen für End-to-End-Tests sowie die hohe Stabilität und Geschwindigkeit der Testausführung.

Durch den Einsatz von Playwright konnte die Konsistenz der Benutzeroberfläche (UI) zuverlässig sichergestellt werden. Die automatisierten Tests ermöglichen es, Interaktionen und Darstellungsvarianten reproduzierbar zu prüfen und so frühzeitig Abweichungen oder Fehler zu erkennen. Auf diese Weise trägt das Testing wesentlich zur Qualitätssicherung und Nachhaltigkeit der entwickelten Lösung bei.

## 4.4 Backend

Das Backend wurde mit Node.js und dem minimalistischen Framework Express.js umgesetzt. Express ist das am weitesten verbreitete Node.js-Framework für Webserver und APIs. Es bietet eine ausgereifte Middleware-Architektur, die sehr flexibel und modular ist. Im Vergleich zu ähnlich minimalistischen Frameworks wie Koa, das von den gleichen Entwicklern stammt, bietet Express mehr out-of-the-box Funktionalitäten und eine größere Community mit umfangreichen Plugins und Support. (Community, 2025; Appventurez, 2025)

Koa hingegen ist moderner und basiert stärker auf ES6 Features wie async/await, was den Code oft sauberer macht. Allerdings ist Koa weniger „batteries included“ und erfordert mehr Initialaufwand und zusätzliche Libraries, um Funktionen bereitzustellen, die Express standardmäßig mitbringt. Für dieses Projekt, welches einen schnellen Einstieg, umfangreiche Dokumentation und stabile Middleware braucht, ist Express daher die pragmatischere Wahl. Zudem sind Gruppenmitglieder bereits mit Express vertraut, was die Einarbeitungszeit verkürzt und die Produktivität steigert.

Die Anbindung an eine InfluxDB erfolgt über die offizielle Client-Bibliothek. Neben dem Abrufen historischer Sensorwerte werden auch Funktionen zum Schreiben von

17

Dummy-Daten bereitgestellt. Diese werden, solange die Verbindung zu den wirklichen Sensorwerten noch nicht hergestellt ist, zum Testen verwendet.

Für die Speicherung der Sensordaten wurde InfluxDB gewählt. Eine Zeitreihen-Datenbank, die speziell für viele konsekutive Datenströme optimiert ist. InfluxDB bietet eine simple API und gutes visuelles UI, ohne dass viel Konfiguration nötig ist. Im Vergleich zu einer relationalen Datenbank wie TimescaleDB, die auf PostgreSQL basiert, ist InfluxDB deutlich einfacher zu handhaben und benötigt weniger Overhead für die Konfiguration. Um eine TimescaleDB sicher zum laufen zu bringen, sind komplexe Zugriff-Skripte benötigt, um die Benutzer zu verwalten. InfluxDB hingegen arbeitet mit einem einfachen Benutzer- und Rollenkonzept. Auch für die API-Authentifizierung ist InfluxDB mithilfe von Tokens und Secrets deutlich einfacher zu konfigurieren. Der Rationale Aspekt einer traditionellen ist sicherlich in vieler Hinsicht nützlich, wird aber in diesem Projekt nicht benötigt. Eine nahtlosen Integration in das Node.js-Backend ist mit der offiziellen InfluxDB-Bibliothek kein Problem. InfluxDB wurde uns initial von den "Verteilten SystemeDozenten ausdrücklich empfohlen, da wir viele Zeitwerte speichern und analysieren wollen.

Berechnung des Speicherplatzbedarfs für InfluxDB

Zur Abschätzung des benötigten Speicherplatzes in InfluxDB betrachten wir die anfallenden Sensordaten pro Stunde.

Rohdaten Pro Sekunde werden 10 Messungen von 4 Sensoren erfasst, wobei jeder Wert als double (64 Bit = 8 Byte) gespeichert wird. Damit ergibt sich:

10 × 4 × 8 Byte × 60 × 60 = 1,152,000 Byte ≈ 1.1 MB/h

Base64-kodierte Daten Wird der Algorithmus auf die Sensordaten angewendet, erzeugt er daraus ein 10x10-Array mit Werten im Bereich von 0 bis 255. Dieses Array wird anschließend kodiert. Durch die Base64-Kodierung entsteht dabei ein Overhead von etwa 36%. Für die Datenmenge ergibt sich pro Sekunde:

800 Bit = 100 Byte | ⇒ | mit Overhead ≈ 136 Byte

18

Somit pro Stunde:

136 Byte × 60 × 60 = 489,600 Byte ≈ 470 KB/h

Fazit Für die Speicherung in InfluxDB müssen daher pro Stunde etwa

1.1 MB (Rohdaten) + 0.47 MB (Base64) ≈ 1.6 MB/h

eingeplant werden.

Das Backend ist ebenfalls in einem eigenen Docker-Container gekapselt. Die Kommunikation mit dem Frontend erfolgt über definierte HTTP-Endpunkte im Container-Netzwerk. Diese Trennung verbessert die Wartbarkeit und erlaubt eine flexible Skalierung beider Komponenten unabhängig voneinander.

## 4.5 MQTT Subscriber

Um den Datenfluss zu verfollständigen fehlt eine Brücke zwischen dem MQTT Server und der InfluxDB. Hierfür wird ein sogenannter MQTT-Subscriber benötigt, der die Daten vom MQTT-Broker abonniert und in die InfluxDB schreibt. Technisch gesehen kann dies mit einer vielzahl von Frameworks / Sprachen / Tools umgesetzt werden. Zum Beispiel mit Python, Node.js, Golang oder auch Java. Wir haben uns für Node-RED entschieden, da es eine einfache und schnelle Möglichkeit bietet, um Daten von MQTT zu InfluxDB zu übertragen. Node-RED ist eine visuelle Programmierumgebung, die auf Node.js basiert und es ermöglicht, Datenströme einfach zu verarbeiten und zu transformieren. Besonders das debugging und die Visualisierung der Datenströme ist in Node-RED sehr einfach und intuitiv. (Node-RED, 2025)

Im Vergleich zu z.B. einem Python-Skript ist Node-RED deutlich einfacher zu handhaben. Natürlich ist Node-RED nicht so performant oder bietet dieselbe Flexibilität und Kontrolle wie ein selbstgeschriebenes Skript, ist aber dafür deutlich einfacher zu konfigurieren und zu warten. Besonders in unserem spezifischen Fall, wo wenig Kontrolle über den schlussendlichen Server besteht, ist Node-RED eine gute Wahl. Eine automatische Ausführung von Skripten ist beinahe unmöglich, das keine Kontrolle über Sudo-Level Systemdiensten besteht.

19

### 4.5.1 NodeRED Umsetzung

Node-RED stellte sich als eine gute Entscheidung heraus, um den Flow zwischen MQTT und InfluxDB zu realisieren, und aber auch um bspw. Statusanfragen für die Admin-Seite zu beantworten. Das einzige Manko war das ständige Erneuern der Tokens für die InfluxDB, da Node-RED keine Möglichkeit bietet, Umgebungsvariablen zu verwenden. Schlussendlich entstand ein gut-funktionierender Flow:


20

# 5 Befestigung der Hardware

Um die Hardware des AudiTim-Systems sicher und stabil zu befestigen, sind verschiedene Montagemöglichkeiten verfügbar. Ein Großes Problem bei vorgefertigten halterungen ist jedoch, dass diese oft an die and geschraubt oder anderweitig befestigt werden müssen. Daher fiel für unser Projekt die wahl auf eine selbst designte Halterung, welche in einem 3D-Drucker hergestellt werden kann. Dies Garantiert dass keine schäden an der Hardware oder am Raum in welchem die Hardware montiert wird entstehen.

## 5.1 Platzungskonzept

Aus akustischer Sicht liefern Messungen die zuverlässigsten Ergebnisse, wenn die Sensoren auf Kopfhöhe im Sitzen ( 1,2-1,5 m Höhe) angebracht sind und mindestens 1 Meter Abstand zu Wänden und der Schallquelle haben. Dieses Vorgehen minimiert frühe Reflexionen, stehende Wellen und lokale Pegelabweichungen - Faktoren, die die Messgenauigkeit maßgeblich beeinträchtigen (Oltheten, 2019) . Leider ist diese ideale Positionierung in unserem Fall praktisch nicht umsetzbar. So birgt Montage am Boden, Tischen oder gesonderte SStänderërhöhte Gefahr von Beschädigungen, Verschiebungen und Manipulation. An der Decke jedoch beifinden sich bereits vorhandene Löcher; diese können genutzt werden, um die Sensoren und den Mikrocontroller sicher zu befestigen. Auch den einen Meter Abstand zu Wänden und Schallquellen kann so eingehalten werden. Dieser Kompromiss ermöglicht eine schützende, wartungsarme und vergleichbare Positionierung der Sensoren. So bleibt der Messaufbau reproduzierbar, sicher und funktional, auch wenn die akustisch ideale Lösung nicht vollständig umsetzbar ist.

21

## 5.2 Deckenhalterung

Um die Hardware an der Decke zu befestigen, wurde eine spezielle Halterung entworfen, die eine sichere Montage ermöglicht. Diese Halterung nutzt die in den Decken vorhandenen "Löcher"für die Montage und wurde als eine Art Pin konzipiert.


Der in den Bildern Dargestellte Pin kann durch den Spalt in der Mitte in die öffnung der Decke gesteckt werden. Durch die Konische form der Spitze des Pins wird garantiert dass dieser auch bei der Demontage des Projekts keine schäden hinterlässt. Das runde loch welches sich durch den Pin zieht dient dazu, den Pin mit einer Schraube an der Hardware zu befestigen.

## 5.3 ESP32-Halterung

Der Esp benötigt eine Box welche sicher an der Decke mit den Pins befestigt werden kann. Bei dem Design der Box wurde sich an einigen Vorlagen orientiert um eine

22


optimale Passform zu gewährleisten. Die Box ist so gestaltet, dass sie den ESP32 sicher hält und gleichzeitig genug Platz für die Verkabelung bietet.

Die angesprochenen löcher der Pins kommen in der Decke der Box zum Einsatz, um die Box sicher an der Decke zu befestigen. Diese werden durch die löcher in der Decke mit schrauben von innen befestigt.

23

## 5.4 Sensor-Halterung

Die Sensorhalterung wurde so entworfen dass sie platz für einen möglichen Dämpfer bietet, welcher um das Mikrofon befestigt werden kann. Auch diese Halterung wird mit den Pins an der Decke befestigt, jedoch wird sie nicht geschraubt sondern direkt mit den Pins gedruckt. Der Sensor wird dann einfach mit zwei schrauben an der Halterung befestigt.


## 5.5 3D-Raummodellierung

Um eine grafische Übersicht der Montage der ESPs und Sensoren zu erhalten, wurde ein 3D-Modell des Raumes erstellt. Außderdem soll dieses später als Grundlage für die Simulation der Schallausbreitung als Hintergrund für die Heatmap im Frontend dienen. Dafür wurde vorerst der Vorlesungsraum ausgemessen und in einer technischen Zeichnung festgehalten:

24


25

Diese Zeichnung dient als Grundlage für die 3D-Modellierung des Raumes, welche in Blender durchgeführt wurde:


Hinweis zur Nutzung der 3D-Modelle Die im Projekt erstellten Blender-Dateien und Halterungen können direkt für den 3D-Druck verwendet werden. Zum Export der STL-Dateien ist im Blender-Menü der Pfad audiTim/Blender/Printable zu wählen.

26

# 6 Algorithmus zur Schallquellenlokalisierung

In diesem Kapitel werden verschiedene Ansätze zur Lokalisierung einer Schallquelle im Raum beschrieben. Die Verfahren unterscheiden sich in ihrer physikalischen Genauigkeit, im Rechenaufwand sowie in der praktischen Umsetzbarkeit. Es werden sowohl rein mathematische Interpolationsverfahren als auch modellbasierte und lernbasierte Methoden betrachtet.

## 6.1 Grundprinzipien

Ein präziser, aber aktuell nicht umsetzbarer Ansatz wäre die Time Difference of Arrival (TDOA) in Kombination mit Beamforming. Dabei wird die Zeitdifferenz der Schallausbreitung zwischen mehreren Mikrofonen gemessen. Über Verfahren wie Trilateration oder GCC-PHAT lassen sich daraus Einfallswinkel und Quelle berechnen. Da die vorhandene Hardware jedoch keine ausreichend genaue Zeitmessung erlaubt, konnte dieser Ansatz bislang nicht praktisch umgesetzt werden.

## 6.2 Betrachtete Verfahren

Bilineare Interpolation: Aus den vier Eckpunkten eines Messrasters wird durch zweifache lineare Interpolation eine flache Ebene gebildet. Dies liefert eine gleichmäßige, symmetrische Heatmap, berücksichtigt jedoch keinerlei physikalische Eigenschaften der Schallausbreitung. Damit eignet sich die Methode eher zur Visualisierung als zur tatsächlichen Lokalisierung.

27 for (let row = 0; row < 10; row++) {

const y = row / 9;

const rowData = [];

for (let col = 0; col < 10; col++) {

const x = col / 9;

const V =

sensorValues.d1 * (1 - x) * (1 - y) +

sensorValues.d2 * x * (1 - y) +

sensorValues.d3 * (1 - x) * y +

sensorValues.d4 * x * y;

rowData.push(Number(V.toFixed(2)));

}

grid.push(rowData);

}

Listing 6.1: Bilineare Interpolation


Inverse Distance Weighting (IDW): Hierbei wird der Einfluss eines Sensors umgekehrt proportional zur Distanz zur betrachteten Position gewichtet, häufig mit einem Distanzexponenten von p = 2 (inverse quadratische Gewichtung). Das Ergebnis ist eine weiche Heatmap, deren Maximum meist in der Nähe der lautesten Sensoren liegt. Bei mehreren Schallquellen oder komplexer Raumakustik verschwimmt jedoch das Ergebnis.

28 const power = 2; // Distanzexponent

for (let row = 0; row < 10; row++) {

const y = row / 9;

const rowData = [];

for (let col = 0; col < 10; col++) {

const x = col / 9;

let numerator = 0, denominator = 0;

for (const [key, { x: sx, y: sy }] of Object.entries(

sensorPositions)) {

const value = sensorValues[key];

const dx = x - sx;

const dy = y - sy;

const distance = Math.sqrt(dx * dx + dy * dy) || 0.0001;

const weight = 1 / Math.pow(distance, power);

numerator += value * weight;

denominator += weight;

}

rowData.push(Number((numerator / denominator).toFixed(2)));

}

grid.push(rowData);

}

Listing 6.2: Inverse Distance Weighting


29

Physikalisches Modell – Rückwärtsprojektion: Für jeden Punkt im Raum wird der erwartete Pegel an jedem Mikrofon berechnet:

L = L0 − 20 · log10(d)

mit d als Abstand zwischen Quelle und Mikrofon. Anschließend werden die berechneten Werte mit den real gemessenen Pegeln verglichen und die Abweichungen gespeichert. Eine Heatmap zeigt die Positionen mit den geringsten Fehlern als wahrscheinlichste Quelle an.

Maximum Likelihood Estimation (MLE): Dieser statistische Ansatz modelliert die Wahrscheinlichkeit, dass eine Quelle an Position (x, y) die gemessenen Pegel si erzeugt:

P =

Yn

i=1

1
√
2πσ²
- exp
−

(si − (L0 − 20 log10 di))² 2σ

2

Der Punkt mit der höchsten Wahrscheinlichkeit wird als Quellenposition angenommen. Das Verfahren ist robust gegenüber Rauschen, erfordert jedoch ein präzises Modell für Messfehler.

Weighted Centroid Localization (WCL): Jeder Sensorwert wirkt wie eine „Gravitationskraft“, die die geschätzte Quelle in seine Richtung zieht. Durch Berechnung des gewichteten Mittelpunkts aller Sensoren lässt sich eine einzelne (x, y)-Position bestimmen, die den Schwerpunkt der Schallstärke darstellt. Gut geeignet, wenn ein dominanter Bereich im Raum deutlich lauter ist.

1 | power = 2;
2 | for (const [key, { x, y }] of Object.entries(sensorPositions)) {
3 | const value = sensorValues[key];
4 | const weight = Math.pow(value, power);
5 | weightedX += x * weight;
6 | weightedY += y * weight;
7 | weightSum += weight;
8 | }

Listing 6.3: Weighted Centroid Localization (WCL)

30


Machine Learning: Durch Training eines Modells (z. B. KNN, Random Forest, MLP) mit bekannten Quellenpositionen und zugehörigen Pegelwerten kann die Quellenposition direkt aus den Messwerten vorhergesagt werden. Bei guter Trainingsbasis liefert dies sehr schnelle und präzise Ergebnisse. Allerdings sind umfangreiche und repräsentative Trainingsdaten erforderlich.

Kombinierter IDW-WCL-Ansatz: Zur Verbesserung der Lokalisierungsgenauigkeit wird zunächst eine IDW-Heatmap berechnet. Anschließend wird der durch WCL ermittelte Schwerpunkt durch einen zusätzlichen Peak (z. B. Gauß-Blob) verstärkt und in die Heatmap eingeblendet. Dadurch lassen sich weiche Verteilungen mit einem klaren Maximum kombinieren.

1 | for (let row = 0; row < gridSize; row++) {
2 | const y = row / (gridSize - 1);
3 | const rowData = [];

4
5 | for (let col = 0; col < gridSize; col++) {
6 | const x = col / (gridSize - 1);
7 | let numerator = 0;
8 | let denominator = 0;

9
10 | for (const point of interpolationPoints) {
11 | const dx = x - point.x;
12 | const dy = y - point.y;
13 | const distance = Math.sqrt(dx * dx + dy * dy) || epsilon;

31

14 | const weight = 1 / Math.pow(distance, idwFlatteningPower);
15 | numerator += point.value * weight;
16 | denominator += weight;
17 | }

18
19 | const interpolatedValue = numerator / denominator;
20 | rowData.push(Number(interpolatedValue.toFixed(2)));
21 | }

22
23 | grid.push(rowData);
24 | }

Listing 6.4: Kombinierter IDW-WCL-Ansatz


32

## 6.3 Vergleich der Verfahren

Methode | Typ | Vorteile | Nachteile | Quelle be-stimmbar?
Bilineare Interpolation | Interpolation | Schnell, symme-trische Heatmap | Kein physikali-scher Bezug | Ungefähr
IDW | Interpolation | Einfach, intuitiv, glatte Heatmap | Kein klares Ma-ximum | Ungefähr
Physikalisches Modell | Modellbasiert | Realitätsnah | Rechenintensiv, Annahmen nötig | Ja (Heat-map)
MLE | Wahrscheinlichkeit | Robust, statis-tisch fundiert | Modell für Feh-ler nötig | Ja (Wahr-scheinlich-keit)
WCL | Schätzwert | Einfach, schnel-ler Indikator | Ungenau bei asymmetri-schen Verteilun-gen | Ja (Koordi-nate)
Machine Learning | Lernbasiert | Sehr schnell nach Training | Trainingsdaten nötig | Ja (xy di-rekt)

## 6.4 Fazit

Aus den Tests ergeben sich folgende Tendenzen:

- Machine Learning liefert bei guter Umsetzung die besten Ergebnisse, ist jedoch mit hohem Initialaufwand verbunden.
- WCL eignet sich gut, um den ungefähren Lautstärkenschwerpunkt im Raum zu bestimmen.
- IDW ist hilfreich, um Unterschiede in der Schallverteilung („hinten lauter als vorne“) darzustellen.
- MLE bietet hohes Potenzial für präzise Ortung, ist jedoch rechenintensiv und komplex in der Parametrisierung.

33

Eine Kombination aus IDW und WCL hat sich als vielversprechend erwiesen, um eine aussagekräftige Heatmap mit einem klar erkennbaren Maximum zu erzeugen. Zudem ist diese Methode relativ einfach zu implementieren und benötigt keine aufwändige Kalibrierung. Die Heatmap wird mit aktuellen Daten getestet, somit kann der Algorythmus durch die gewichtung von IDW und WCL angepasst werden.

34

# 7 API-Kommunikation

In diesem Kapitel wird die Kommunikation zwischen Frontend und Backend beschrieben, insbesondere die Übertragung von Heatmap-Daten. Es werden verschiedene Ansätze zur Datenübertragung und -kompression vorgestellt, um die Effizienz und Performance der Anwendung zu optimieren.

## 7.1 Problemstellung

Wenn für jede Slider-Position eine API-Abfrage durchgeführt wird:

- Bei einer Frequenz von 10 Hz (alle 100 ms ein Datenpaket) ergeben sich 36,000 Zeitpunkte pro Sensor und somit 144,000 Werte pro Stunde.
- Beispielrechnung: 36,000 × 10 × 10 = 3,6 Millionen Werte für ein 10 × 10-Array.

## 7.2 Datenbasis

- Heatmap-Größe: 10 × 10 Werte (100 Felder pro Heatmap)
- Datentyp: Float16 (2 Byte pro Wert)
- Frequenz: 10 Hz (alle 100 ms ein Frame)
- Beispiel: 1 Stunde = 3,600 Sekunden = 36,000 Frames

Speicherbedarf (unkomprimiert):

100 · 2 Bytes = 200 Bytes/Frame

200 · 36,000 = 7,200,000 Bytes ≈ 7.2 MB

35

## 7.3 Optimierungsoptionen

1. Downsampling (Mittelwert pro Sekunde)
3,600 Frames/h 3,600 × 100 Werte = 0.72 MB. Vorteil: geringe Datenmenge, einfaches JSON; Nachteil: Peaks nicht sichtbar.
2. Textkompression (Gzip/Brotli)
Reduktion auf ca. 15–25 % ≈ 1.8 MB.
3. Binärformate (MessagePack, Protobuf, FlatBuffers) 30–40 % Ersparnis gegenüber JSON ≈ 5.0 MB.
4. Binär + Kompression
Kombination aus beidem ≈ 1.2 MB.
5. Delta-Encoding (nur Änderungen)
Angenommen: jeder 3. Wert ändert sich ≈ 3.4 MB.
6. Delta-Encoding + Kompression
Weitere Reduktion auf ≈ 1.0–1.2 MB.
7. Pre-Exportierte Dateien
Backend exportiert pro Stunde eine Datei ≈ 7.2 MB.
8. Pre-Export + Kompression
Speicherbedarf: ≈ 1.2 MB/h; sehr performant und cachebar.

36

## 7.4 Vergleich der Ansätze

Beschreibung | Speicher/h | Vorteile | Nachteile
Mittelwert pro Sekunde (Downsampling) | ≈ 0.72 MB | Sehr leicht, JSON möglich, wenig Traffic | Daten stark geglättet, Peaks nicht sichtbar
JSON + Gzip/Brotli | ≈ 1.8 MB | Einfach umsetzbar, keine großen Änderungen | Höhere Lesezeit, trotzdem noch Textformat
Binärformat | ≈ 5.0 MB | Schnell zu dekodieren, we-niger Overhead | Komplexere Integration im Frontend
Binär + Kompression | ≈ 1.2 MB | Gute Mischung aus Effizi-enz & Geschwindigkeit | Backend-Implementierung auf-wändiger
Delta-Encoding | ≈ 3.5 MB | Ideal bei geringen Ände-rungen | Schlecht bei stark variablen Daten
Delta + Kompression | 1.0–1.2 MB | Sehr gute Kompression | Schwer zu debuggen, kom-plex
Pre-Export (roh) | ≈ 7.2 MB | Kein Runtime-Rechenaufwand, einfaches Caching | Hoher Speicherbedarf
Pre-Export + Kompression | ≈ 1.2 MB | Sehr performant, cachebar, ideal für Slider | Dateiverwaltung nötig

## Fazit

Aufgrund der hohen Komplexität und der großen Datenmengen ist es sinnvoll, die Heatmap-Arrays in einer separaten Datenbasis zu speichern. Das Frontend erhält die Daten in vorverarbeiteter Form durch Downsampling, um die Übertragungsmenge zu reduzieren und die Darstellungsgeschwindigkeit zu erhöhen. Zusätzlich wird eine Komprimierung der Daten in Betracht gezogen, um den Speicher- und Bandbreitenbedarf weiter zu minimieren, ohne die wesentliche Aussagekraft der Werte zu verlieren.

37

# Literaturverzeichnis

Appventurez (2025), ‘Node.js frameworks comparison: Express.js, koa.js, and more’. Accessed: 2025-08-01.
URL: https://www.appventurez.com/blog/node-js-framework

Community, B. (2025), ‘Koa.js vs express.js: Which node.js framework to choose?’. Accessed: 2025-08-01.
URL: https://betterstack.com/community/guides/scaling-nodejs/koajs-vs-expressjs

Node-RED (2025), ‘Node-red dokumentation’. Accessed: 2025-08-14.
URL: https://nodered.org/docs/

Oltheten, W. (2019), ‘The 7 steps of ideal mic placement’. Accessed: 2025-07-31.
URL: https://sonicscoop.com/7-steps-for-ideal-mic-placement/

Powell, Z. (2023), ‘Angular vs. react: Ein detaillierter vergleich’. Accessed: 2025-08-14. URL: https://kinsta.com/de/blog/angular-vs-react/

i

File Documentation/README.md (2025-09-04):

# 📄 Projektdokumentation – SE-Projekt DHBW

## 📁 Verzeichnisstruktur

- `ProjektSe/`: Enthält das LaTeX-Template der DHBW, auf dem die gesamte Dokumentation basiert
- `dokumentation.tex`: Main Datei zur PDF-Erzeugung

## ⚙️ Voraussetzungen (für LaTeX)

Zum Bearbeiten und Kompilieren der Dokumentation wird folgendes empfohlen:

- **Visual Studio Code**
- Plugin: `LaTeX Workshop`
- **Perl** (für das DHBW-Template, z. B. zur Seitenanzahlzählung)
- **MiKTeX** oder **TeX Live** (je nach Betriebssystem)

## 🔀 Git-Workflow & Teamregeln

Damit alle effizient zusammenarbeiten können, gelten folgende Regeln für dieses Doku-Repository:

### Allgemeine Regeln

-  Im Normalfall arbeiten alle direkt auf dem `main`-Branch.
-  Bevor Änderungen gepusht werden: Kompiliere lokal, prüfe auf Fehler und achte auf sauberes Layout.
-  Sinnvolle Commit-Nachrichten, z. B. `Kapitel Methodik ergänzt` oder `Tippfehler in Einleitung korrigiert`.
-  **Kein** Commit von generierten Hilfsdateien (z. B. `.lot`, `.aux`, `.log`, etc.). Diese gehören nicht ins Repository (siehe `.gitignore` unten).

### Arbeiten im Team (optional bei paralleler Arbeit)

Falls mehrere Personen gleichzeitig an verschiedenen Teilen schreiben, jeweiligen Branch erstellen.

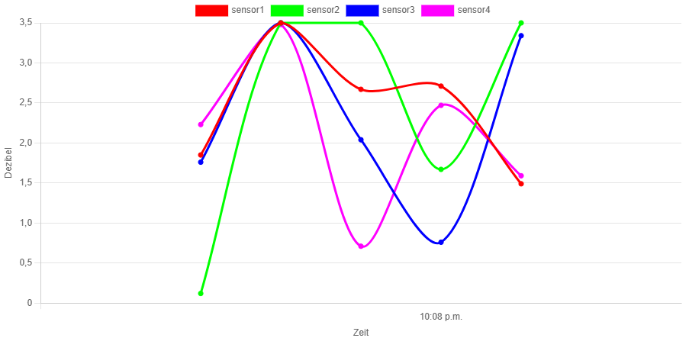
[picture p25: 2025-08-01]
Documentation/ProjektSe/images/LinechartFE.png

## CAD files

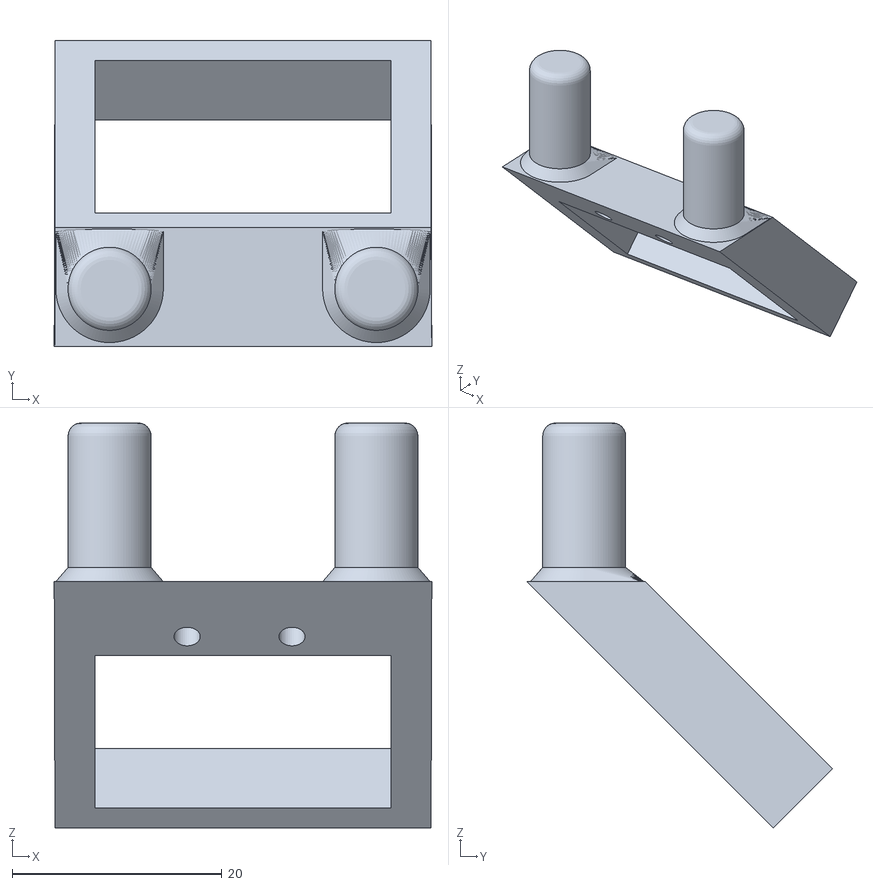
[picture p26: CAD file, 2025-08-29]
Blender/Printable/SensorHolder2.stl
36.0 x 29.1 x 38.6

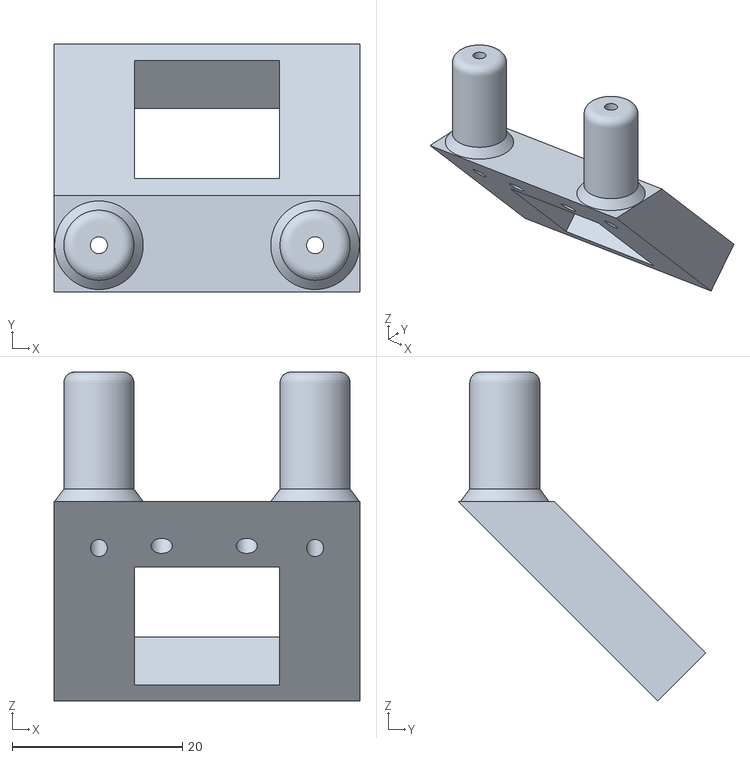
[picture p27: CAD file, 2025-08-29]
Blender/SensorHolder_finprb.stl
36.0 x 29.1 x 38.7

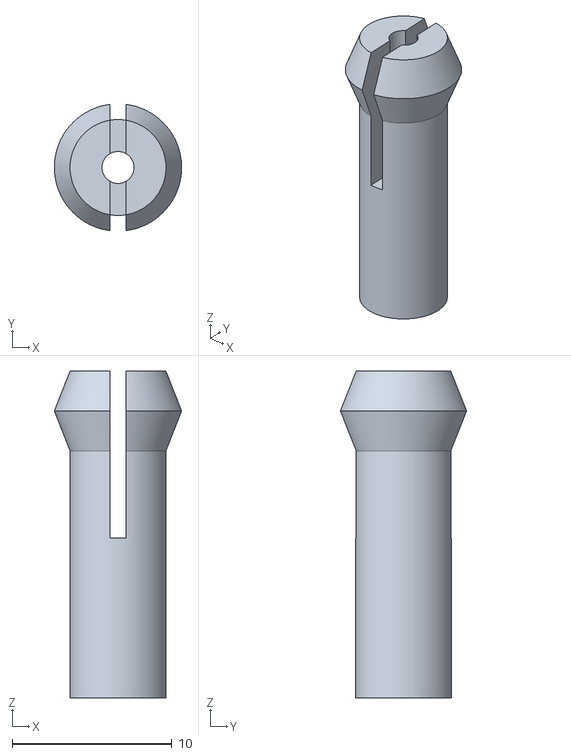
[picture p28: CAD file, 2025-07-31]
Blender/Printable/Pin.stl
7.97 x 7.90 x 20.5

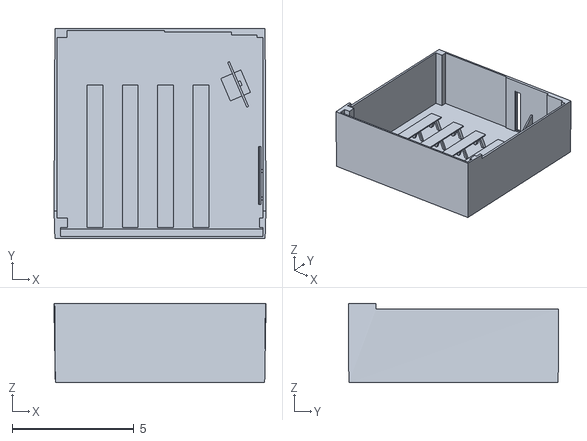
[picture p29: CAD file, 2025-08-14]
Blender/Room.stl
8.70 x 8.63 x 3.25

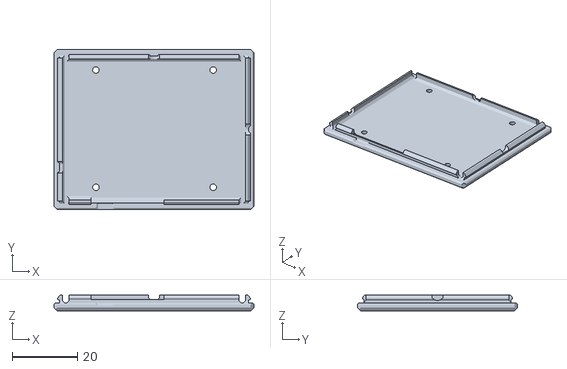
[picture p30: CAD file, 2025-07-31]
Blender/Printable/ESPHolderTop.stl
61.3 x 49.2 x 4.90

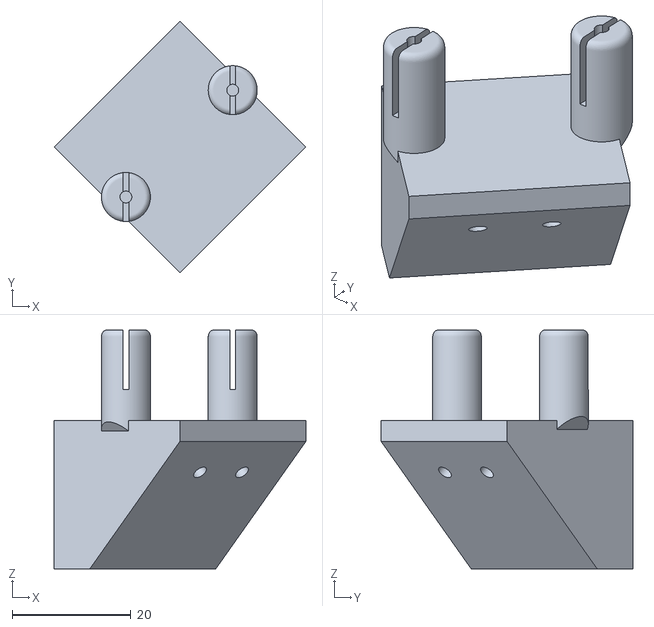
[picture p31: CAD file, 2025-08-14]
Blender/SensorHolderv2.stl
42.4 x 42.4 x 40.2

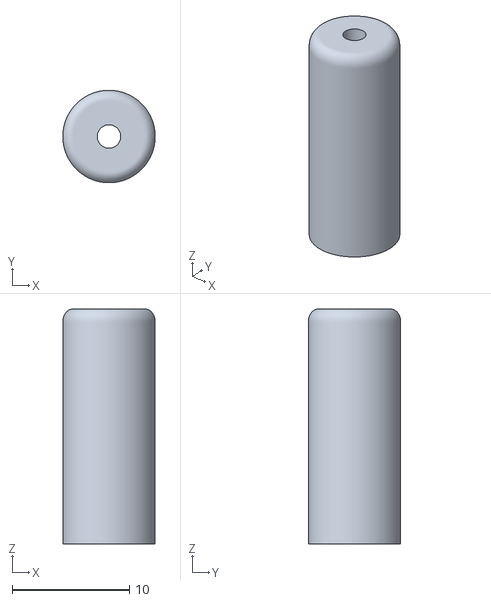
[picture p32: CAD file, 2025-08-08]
Blender/Pinstraightx1_05.stl
7.88 x 7.87 x 20.0

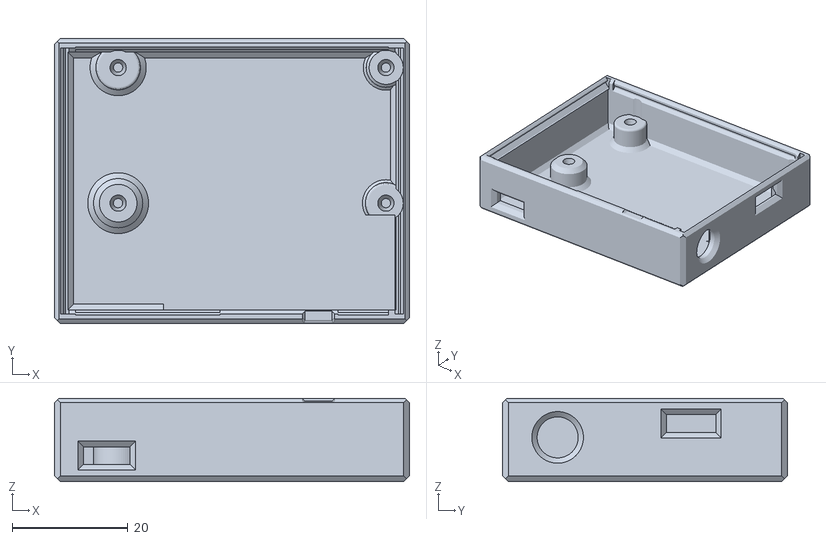
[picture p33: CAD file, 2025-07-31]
Blender/Printable/ESPHolderBottom.stl
61.3 x 49.2 x 14.4

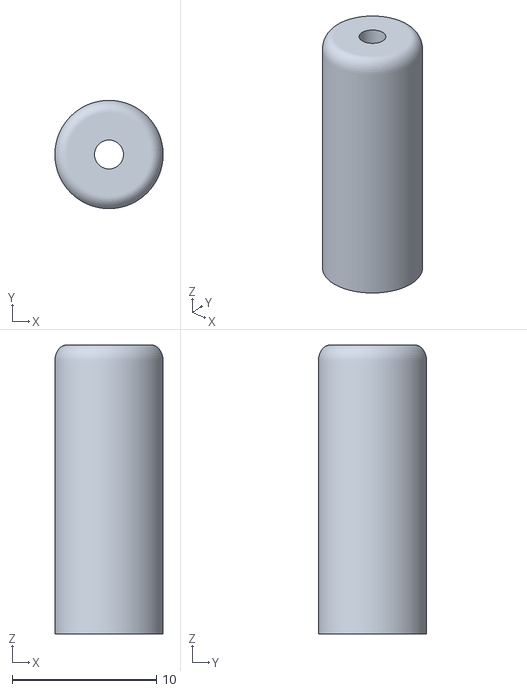
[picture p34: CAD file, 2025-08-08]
Blender/Pinstraightx1.stl
7.50 x 7.50 x 20.0

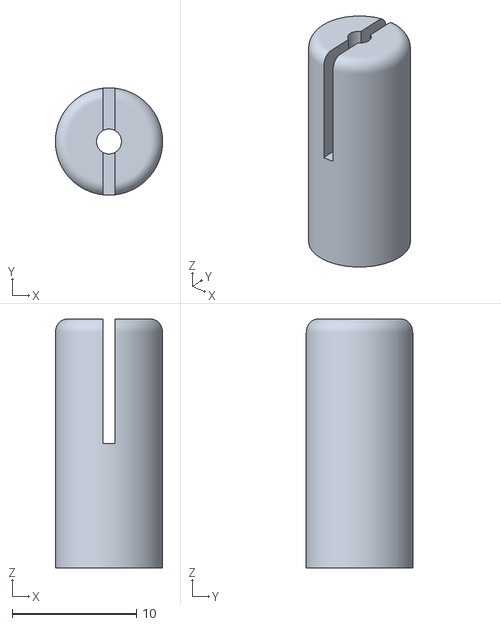
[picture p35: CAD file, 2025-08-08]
Blender/PinstraightWslitx1_15.stl
8.63 x 8.63 x 20.0

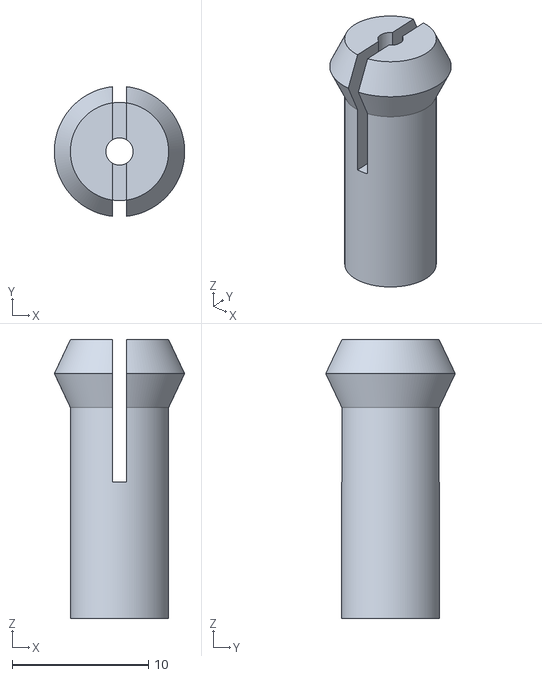
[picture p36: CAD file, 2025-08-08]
Blender/Pinx1_2.stl
9.56 x 9.50 x 20.5

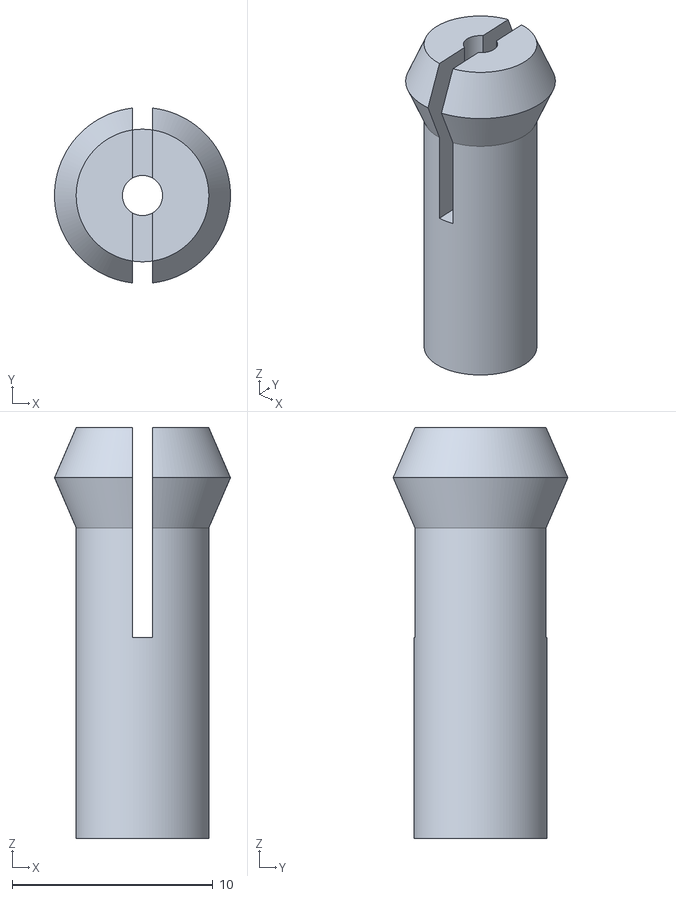
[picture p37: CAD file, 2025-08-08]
Blender/Pinx1_1.stl
8.76 x 8.70 x 20.5

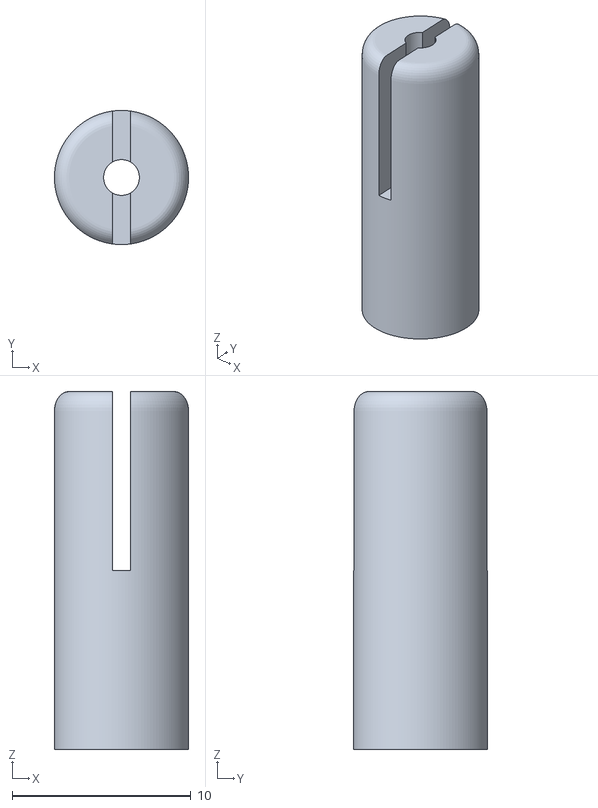
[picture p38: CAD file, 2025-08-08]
Blender/PinstraightWslitx1.stl
7.50 x 7.50 x 20.0

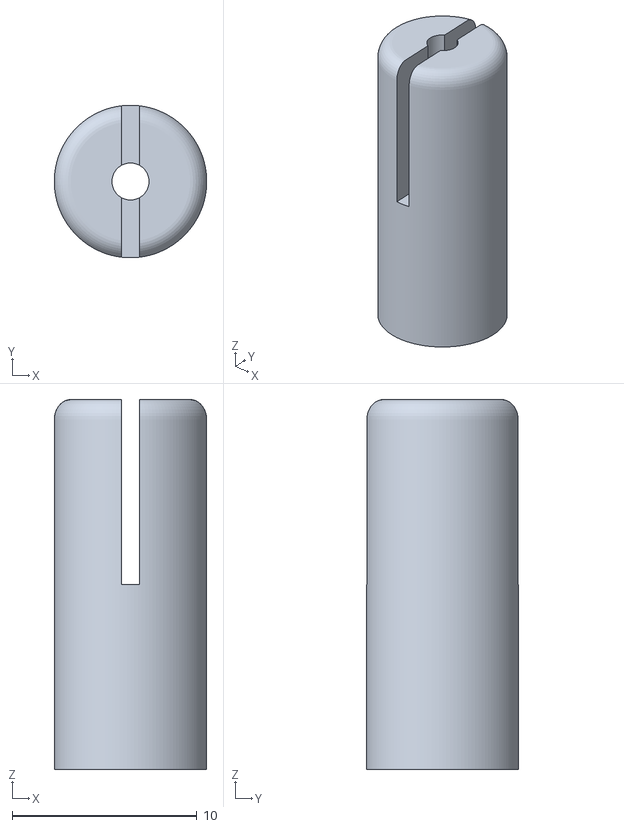
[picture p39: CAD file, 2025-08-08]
Blender/PinstraightWslitx1_1.stl
8.25 x 8.25 x 20.0

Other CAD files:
Blender/PinstraightWslitx1_05.stl
Blender/Pinstraightx1_1.stl
Blender/SensorHolder.stl
Blender/blend/Pin.blend
Blender/blend/Pinstraight.blend
Blender/blend/Room.blend
Blender/blend/SensorHolder.blend
Blender/blend/SensorHolder_finprb.blend

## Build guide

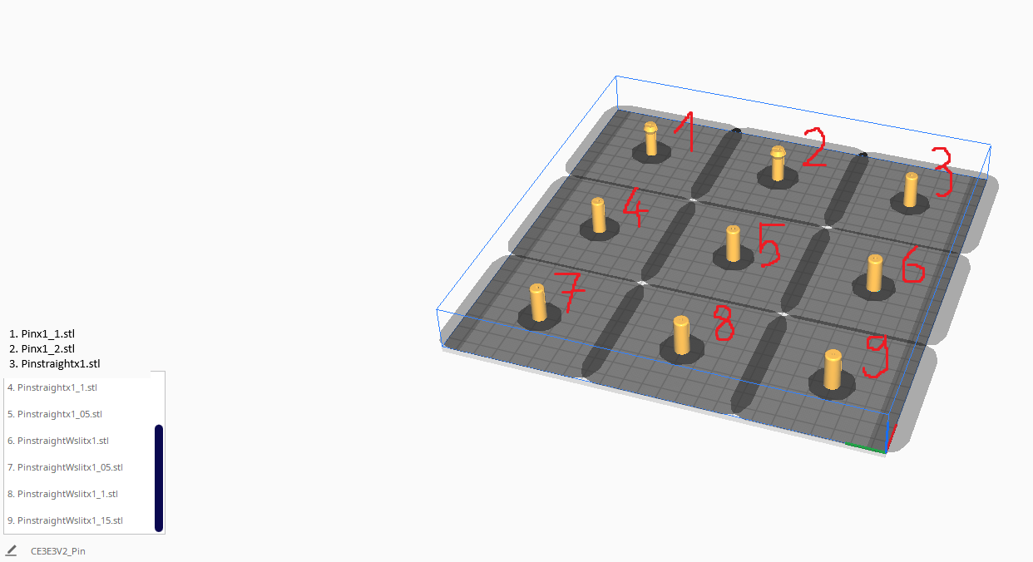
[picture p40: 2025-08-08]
Blender/PNGs/PinTestPrinting.png

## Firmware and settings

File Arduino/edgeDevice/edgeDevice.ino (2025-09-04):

// Installation instructions for the ESP32-Board
// https://randomnerdtutorials.com/installing-the-esp32-board-in-arduino-ide-windows-instructions/

// Boards:
// esp32 by Espressif Systems@3.2.1

// Select ESP32 Dev Module as your board

// Libraries:
// ArduinoMqttClient by Arduino@0.1.8
// ArduinoJson by Benoit@7.4.2

#include <WiFi.h> // Is installed automatically. Don't install additional libs
#include <ArduinoMqttClient.h> // Has to be installed manually
#include <esp_now.h>
#include <esp_wifi.h>
#include "../arduino_secrets.h" // Local file with secrets
#include "time.h" // For Timestamps NTP
#include <ArduinoJson.h> // For MQTT Json

// This sketch is executed on the Edge-Device.
// It connects to WiFi and gives all sensor data from the other ESPs to the MQTT server.
// Sensor data is being captured locally but also received from the other ESPs over ESP-Now.

// Mac-Adresses:
// ESP-1:         94:54:C5:E8:A5:DC -> DE:AD:C0:DE:00:01
// ESP-2:         94:54:C5:E8:BC:40 -> DE:AD:C0:DE:00:02
// ESP-3:         D4:8C:49:69:D5:74 -> DE:AD:C0:DE:00:03
// ESP-4:         D4:8C:49:6A:EC:24 -> DE:AD:C0:DE:00:04
// ESP-5: (Edge)  D4:8C:49:69:A2:F0 -> unchanged

const char ssid[] = SECRET_SSID;    // your network SSID
const char pass[] = SECRET_PASS;    // your network password

// MQTT Settings etc...
WiFiClient espClient;
MqttClient mqttClient(espClient);
int        port     = 1883;
const char topic[]  = "dhbw/ai/si2023/5/max4466/0";
const char MQTT_USER[] = "haenisch";
const char MQTT_PASS[] = "geheim";
const char broker[] = "aicon.dhbw-heidenheim.de";
unsigned long  count = 0;

// ESP-Now
typedef struct struct_message {
  uint16_t audio; // 0-4095 Mic volume
} struct_message; // Typedef

// Collect Data: 4 senders x 10 ticks buffer
uint16_t collectEsp[4][10];
// Track which sender sent data during the current tick
bool dataReceived[4] = {false, false, false, false};
int countEspTicks = 0; 

// JSON
JsonDocument doc;
char jsonString[400];

// NTP 
time_t timestamp;

void setup() {
  // Connect to WiFi (STA)
  connectWPA2();

  // Connect to MQTT Broker
  connectMqtt();
  
  // ESP-Now Initialization
  if (esp_now_init() != ESP_OK) {
    return;
  }
  esp_now_register_recv_cb(onReceive);
}

void loop() {
  for (int i = 0; i < 4; i++) {
    dataReceived[i] = false;
  }

  unsigned long startProbeMillis = millis(); // Each measure and sending cycle will take exactly 100ms

  countEspTicks++;
  if (countEspTicks >= 10){
    countEspTicks = 0;
    sendMqtt(count++);
    for(int i = 0; i < 4; i++){
      for(int j = 0; j < 10; j++){
        collectEsp[i][j] = 0;
      }
    }
  }

  // Non-blocking wait to simulate 100ms measurement cycle
  while((startProbeMillis + 100) > millis()){
    delay(1); // Yield to WiFi/ESP-NOW tasks
  }
}

// ESP-Now receive callback
void onReceive(const esp_now_recv_info* info, const uint8_t* data, int len) {
  uint8_t identifier = info->src_addr[5];

  if (len != sizeof(struct_message)) {
    return;
  }

  struct_message incomingData;
  memcpy(&incomingData, data, sizeof(incomingData));

  int index = identifier - 1;

  if (index >= 0 && index < 4) {
    collectEsp[index][countEspTicks] = incomingData.audio;
    dataReceived[index] = true; // Mark as updated for this tick
  }
}

// Prepare and send MQTT payload
void sendMqtt(int count){
  configTime(0, 0, "de.pool.ntp.org");
  timestamp = time(nullptr);
  doc["timestamp"] = timestamp;

  // Flatten 2D Array -> 1D for JSON
  for (int i = 0; i < 40; i++) {
      doc["value"][i] = *(&collectEsp[0][0] + i); 
  }

  doc["sequence"] = count;
  doc["meta"] = "null";
  serializeJson(doc, jsonString);

  // Ensure connectivity before sending
  while(WiFi.status() != WL_CONNECTED) {
    connectWPA2();
  }

  if (!mqttClient.connected()) {
    mqttClient.stop();
    connectMqtt();
  }

  mqttClient.beginMessage(topic);
  mqttClient.println(jsonString);
  mqttClient.endMessage();
  doc.clear();
}

// Connect to Wi-Fi with retries
void connectWPA2() {
  // Cleanup previous connections
  WiFi.disconnect(true);        // Disconnect from STA
  delay(100);                   // Tactical delay

  // Connect to STA first
  WiFi.mode(WIFI_STA);
  WiFi.begin(ssid, pass);
  
  // Attempt connection for 10 seconds
  unsigned long startTime = millis();
  while (WiFi.status() != WL_CONNECTED && millis() - startTime < 10000) {
    delay(500);
  }
}

// Connect to MQTT Broker with retry logic
void connectMqtt(){
  mqttClient.setUsernamePassword(MQTT_USER, MQTT_PASS);
  while (!mqttClient.connect(broker, port)) {
    delay(1000);
  }
}

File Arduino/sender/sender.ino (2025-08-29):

// Installation instructions for the ESP32-Board
// https://randomnerdtutorials.com/installing-the-esp32-board-in-arduino-ide-windows-instructions/

// Select ESP32 Dev Module as your board

#include <esp_now.h>
#include <WiFi.h>
#include <esp_wifi.h>
#include "../probeMax.h"
#include "../arduino_secrets.h" // Local file with secrets
//#include "../inmp441.h" // I2S Microphone

// This sketch is being executed on the 3 ESPs wich are not connected to wifi.
// They only gather sound values and send them to the Edge-Device using ESP-Now

// Mac-Adresses:
// ESP-1:         94:54:C5:E8:A5:DC -> DE:AD:C0:DE:00:01
// ESP-2:         94:54:C5:E8:BC:40 -> DE:AD:C0:DE:00:02
// ESP-3:         D4:8C:49:69:D5:74 -> DE:AD:C0:DE:00:03
// ESP-4:         D4:8C:49:6A:EC:24 -> DE:AD:C0:DE:00:04
// ESP-5: (Edge)  D4:8C:49:69:A2:F0 -> unchanged

// Dependning on the builtin Mac a custom one is assigned
uint8_t edgeDeviceMac[] = {0xD4, 0x8C, 0x49, 0x69, 0xA2, 0xF0};
uint8_t myMac[] = {0xDE, 0xAD, 0xC0, 0xDE, 0x00, 0x00}; // Will get changed based on the ESP; myMac[5] can be used as identifier

const char ssid[] = SECRET_SSID;    // your network SSID

// Standard channel should be 1 but could change
int targetChannel = 1;

// ESP-Now
typedef struct struct_message {
  uint16_t audio; // 0-4095 Mic volume
} struct_message; // Typedef
struct_message myData; // Create a struct_message called myData

unsigned long failedTransmissionCounter  = 0;

void setup() {
  WiFi.mode(WIFI_STA);
  while (!(WiFi.STA.started())) {
    delay(100);
  } 

  setMac(); // Change MAC adress
  findNewChannel(); // Connect to wifi
}

void loop() {
  unsigned long startProbeMillis = millis(); // Each measure and sending cycle will take exactly 100ms
  uint16_t peakToPeak = probeMax4466();

  // Prepare ESP-NOW message
  myData.audio = peakToPeak;
  esp_now_send(edgeDeviceMac, (uint8_t *) &myData, sizeof(myData));

  // Non-blocking wait
  while((startProbeMillis + 100) > millis()){
    ; // Just chill here for the duration of 100ms
  }

  if(failedTransmissionCounter >= 10){
    findNewChannel();
  }
}

// This function recognizes on wich ESP the code is being executed and changes MAC/Identifier accordingly
void setMac(){
  uint8_t originalMac[6];
  WiFi.macAddress(originalMac);
  switch(originalMac[5]){
    case 0xDC:
      myMac[5] = 0x01;
      break;
    case 0x40:
      myMac[5] = 0x02;
      break;
    case 0x74:
      myMac[5] = 0x03;
      break;
    case 0x24:
      myMac[5] = 0x04;
      break;      
  }

  if(myMac[5] != 0){
    esp_wifi_set_mac(WIFI_IF_STA, myMac); // Change local MAC-Adress
  }
}

// Callback espNOW when message has been sent
void onSent(const uint8_t *mac_addr, esp_now_send_status_t status) {
  if(status == ESP_NOW_SEND_SUCCESS){
    failedTransmissionCounter = 0;
  }
  else if(status != ESP_NOW_SEND_SUCCESS){
    failedTransmissionCounter++;
  }
}

void findNewChannel(){
  // Scan for WiFi networks
  int n = WiFi.scanNetworks();
  delay(100);  // Taktischer Delay
  for (int i = 0; i < n; i++) {
    if (WiFi.SSID(i) == ssid) {
      targetChannel = WiFi.channel(i);// Set channel to the same as Edge
      break;
    }
  }
  // Aktuellen Channel setzen
  esp_wifi_set_promiscuous(true);
  esp_wifi_set_channel(targetChannel, WIFI_SECOND_CHAN_NONE);
  esp_wifi_set_promiscuous(false);

  // ESP-Now neu starten, da Kanal sich geändert hat
  esp_now_deinit();
  esp_now_init();

  // Peer wieder hinzufügen
  esp_now_peer_info_t peerInfo = {};
  memcpy(peerInfo.peer_addr, edgeDeviceMac, 6);
  peerInfo.channel = 0;
  peerInfo.encrypt = false;
  esp_now_add_peer(&peerInfo);

  // Callback erneut registrieren
  esp_now_register_send_cb(onSent);
}

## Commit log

2025-07-15 display current lib versions at start
2025-07-16 working sensor capture both Mics
2025-07-21 make ready for receiver sender switch
2025-07-22 fixed wait func and more
    [audiTim.ino, sender.ino]
2025-07-23 remove LED and logs on the sender
2025-07-27 Decrease max mic value and unify probe function
2025-07-28 MQTT not working but push
    [audiTim.ino]
2025-07-31 started Blender Work
    [Pin.blend]
2025-07-31 added Sensor and ESP holder
    [SensorHolder.blend]
2025-07-31 updated Sensor&Esp Holder, added STL
    [ESPHolderBottom.stl, ESPHolderTop.stl, Pin.stl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]
2025-08-01 move Arduino files to subfolder
2025-08-01 re Added Heatmap (Edited initial budged for heatmap)
2025-08-05 Channel auslesen und Senden - NOCH NICHT AUTOMATISCH
2025-08-05 all sensors in db
2025-08-06 Added Room Blend
    [Room.blend]
2025-08-06 Room better
    [Room.blend]
2025-08-06 edited notes
    [Pinstraight.blend, PinstraightWslitx1.stl, PinstraightWslitx1_05.stl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]
2025-08-14 ich weiß auch nicht alte changes
    [Room.stl, SensorHolder.blend, SensorHolder_finprb.blend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]
2025-08-14 added schieberegler mit funktionierender 10 daten schiebung der heatmap (mockdaten)
2025-08-14 bootstrap & working heatmap
    heatmap schieberegler flüssig
2025-08-17 addet Test API calls for Heatmap Array DB
2025-08-21 Live Sensor 2D
2025-08-21 mount file at runtime as read only
2025-08-22 clean model and stl
    [SensorHolder_finprb.blend, SensorHolder_finprb.stl]
2025-08-22 endlich jds flow fixed
2025-08-22 Add Device 5 and cleanup
2025-08-22 got heatmap live
2025-08-22 Avg Heatmap added
2025-08-22 heatmap fix
2025-08-22 update flow for testing
2025-08-24 slightly bigger hole for mic
    [SensorHolder_finprb.blend, SensorHolder_finprb.stl]
2025-08-25 Added Room bg to 3d plot
    [Room.blend]
2025-08-25 make cylinder smaller
    [SensorHolder_finprb.blend]
2025-08-25 added heatmap bg fix and Peakmap w bg
    [Room.blend]
2025-08-26 changed mock value
    [Room.blend]
2025-08-26 better pins and model upgrades
    [SensorHolder2.stl, SensorHolder_finprb.blend]
2025-08-28 Added AlertWatcher for sensor_1
    new container with AlertWatcher, which sends a notification to a discord chanel, if a sensor sends no or wrong values
2025-08-28 alerts for all 4 sensors
2025-09-04 move blender files
    [ESPHolderBottom.stl, ESPHolderTop.stl, Pin.blend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]
2025-09-05 fix accidentally broken heatmap
2025-09-12 adjust live Heatmap/Peekmap to Europe/Berlin timezone
